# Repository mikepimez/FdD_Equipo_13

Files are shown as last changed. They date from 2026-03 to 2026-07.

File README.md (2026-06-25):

# 🌍 Equipo 13 — Fundamentos de Diseño ✦  ⁺
### Carreras de Ingeniería Ambiental / Informática / Industrial  
**Universidad Peruana Cayetano Heredia**

---

## I. Identidad & Propósito  

### 🧭 Propuesta de Valor — Diseñar para la autonomía

En el contexto urbano actual, la calidad del aire no es una condición garantizada, sino una variable invisible que afecta directamente la salud, el rendimiento cognitivo y la calidad de vida de las personas. En ciudades como Lima Metropolitana, la exposición constante a Material Particulado (PM2.5 y PM10) y a elevadas concentraciones de CO₂ en espacios cerrados configura un escenario donde respirar aire limpio deja de ser un derecho efectivo y se convierte en una condición desigual.

Diversos estudios evidencian que, incluso cuando los valores diarios no superan los estándares nacionales, los promedios anuales de contaminantes sí exceden las recomendaciones internacionales, particularmente las establecidas por la Organización Mundial de la Salud. Esta exposición prolongada incrementa el riesgo de enfermedades respiratorias, deterioro cognitivo y reducción del bienestar general.

Frente a esta realidad, nuestro enfoque no se orienta a soluciones dependientes del usuario o del contexto privilegiado, sino a sistemas capaces de operar de manera autónoma, adaptándose a entornos donde la ventilación natural resulta insuficiente o ineficiente.

Diseñamos para reducir la dependencia del comportamiento humano como factor de control ambiental, trasladando la responsabilidad hacia sistemas inteligentes que garanticen condiciones mínimas de salubridad en espacios de alta densidad.

---

### 🎯 Misión del Equipo  

Como Equipo 13, asumimos el compromiso de desarrollar soluciones de ingeniería que integren tecnología, sostenibilidad y responsabilidad social, orientadas a la protección de la salud pública en entornos urbanos.

Nuestra misión es diseñar sistemas accesibles, funcionales y técnicamente sustentados que permitan mejorar la calidad del aire en espacios cerrados, priorizando la prevención de riesgos sobre la reacción tardía. Buscamos que nuestras propuestas no solo respondan a una necesidad técnica, sino que también sean viables en contextos reales donde los recursos son limitados y las condiciones ambientales adversas.

Entendemos la ingeniería no solo como una disciplina de resolución de problemas, sino como una herramienta para reducir brechas, fortalecer la equidad y contribuir a una mejor calidad de vida.

---

### ⚙️ Enfoque de Ingeniería

Nuestro enfoque se basa en la integración de tres principios fundamentales:

- **Monitoreo en tiempo real:**  
  Evaluación continua de variables críticas como concentración de CO₂, presencia de material particulado y condiciones térmicas, utilizando sensores accesibles y calibrables.

- **Procesamiento autónomo:**  
  Implementación de sistemas de control basados en microcontroladores que permitan la toma de decisiones sin intervención constante del usuario.

- **Actuación eficiente:**  
  Activación de mecanismos de ventilación y filtración que respondan dinámicamente a las condiciones del ambiente, garantizando la renovación del aire en tiempos óptimos.

Este enfoque permite transformar datos ambientales en acciones concretas, asegurando que el sistema no solo informe sobre la calidad del aire, sino que intervenga activamente para mejorarla.

---

### 🌱 Enfoque Social & Ambiental  

El proyecto se alinea con una visión de ingeniería centrada en las personas, donde la tecnología no se desarrolla como un fin en sí mismo, sino como un medio para enfrentar problemáticas reales que afectan a la población.

La calidad del aire en espacios interiores es un problema silencioso pero crítico, especialmente en contextos educativos, transporte público y viviendas urbanas densamente ocupadas. Abordarlo implica reconocer que la salud ambiental y la salud humana están profundamente interconectadas.

Por ello, nuestro trabajo busca generar una solución que no solo sea técnicamente viable, sino también socialmente relevante, promoviendo entornos más seguros, saludables y sostenibles.

---

## II. Diagnóstico Técnico & Contextual del Problema
### 2.1 Contexto Ambiental en Lima Metropolitana

La calidad del aire en Lima Metropolitana constituye un problema estructural persistente, caracterizado por la presencia sostenida de material particulado (PM10 y PM2.5) en concentraciones que exceden los límites recomendados por organismos internacionales.

El estudio de Valdivia (2016) evidencia que, si bien los promedios diarios de PM10 pueden mantenerse dentro de los Estándares Nacionales de Calidad Ambiental (ENCA), los promedios anuales de PM10 y PM2.5 superan de manera significativa tanto los estándares nacionales como las guías de la Organización Mundial de la Salud (OMS). Esto genera una falsa percepción de seguridad normativa, ocultando que es la exposición crónica la que representa el verdadero riesgo para la salud

Asimismo, investigaciones basadas en información satelital (Oropeza & Díez, 2022) indican que Lima presenta concentraciones promedio de PM2.5 cercanas a 28 µg/m³, posicionándola entre las ciudades con mayor contaminación en Latinoamérica. Este fenómeno se ve agravado por factores meteorológicos que influyen en la dispersión de contaminantes, como la velocidad del viento y la humedad relativa (Rojas et al., 2022).

Adicionalmente, informes del Organismo de Evaluación y Fiscalización Ambiental (OEFA) han demostrado que el material particulado puede desplazarse desde fuentes industriales hacia zonas urbanas, alcanzando concentraciones superiores a 100 µg/m³ en áreas pobladas, lo que evidencia la limitada capacidad de control del entorno frente a la contaminación atmosférica.

---

### 2.2 Limitaciones de la Ventilación Natural

En entornos educativos y laborales, la ventilación natural continúa siendo la estrategia predominante para la renovación del aire. Sin embargo, su efectividad depende de variables externas como condiciones climáticas, diseño arquitectónico y comportamiento del usuario.

Estudios en contextos similares al latinoamericano (Díaz et al., 2021) demuestran que en aulas con ventilación natural, las concentraciones de CO₂ superan frecuentemente los 1400 ppm, alcanzando picos de hasta 5000 ppm en condiciones de alta ocupación. Estos valores exceden ampliamente el umbral recomendado de 1000 ppm establecido por estándares internacionales como ASHRAE.

Por otro lado, investigaciones realizadas en instituciones educativas peruanas (Huerta, 2018) evidencian que un alto porcentaje de infraestructura presenta deficiencias en estrategias pasivas de ventilación, requiriendo intervenciones adicionales para alcanzar condiciones aceptables de confort térmico.

Asimismo, evaluaciones de confort térmico en aulas universitarias (Alexander & Rivera, 2022) muestran que más del 70% de los usuarios presentan insatisfacción en ambientes sin ventilación activa, con temperaturas que superan los 27°C, lo cual afecta directamente el bienestar de los ocupantes.

Estos resultados confirman que la ventilación natural, por sí sola, no garantiza condiciones adecuadas de calidad de aire ni de confort térmico en entornos de alta ocupación.

---

### 2.3 Impacto en la Salud & Rendimiento Cognitivo

La calidad del aire interior tiene un impacto directo en la salud y en el desempeño cognitivo de los usuarios. El estudio de Satish et al. (2012) demuestra que concentraciones de CO₂ de 1000 ppm generan deterioros significativos en la toma de decisiones, mientras que niveles de 2500 ppm producen reducciones severas en múltiples indicadores cognitivos.

De manera complementaria, investigaciones en entornos escolares (Bakó-Biró et al., 2012) evidencian que el aumento en las tasas de ventilación mejora significativamente la memoria, la velocidad de respuesta y la capacidad de atención de los estudiantes.

Asimismo, estudios como el de Coley et al. (2007) indican que altos niveles de CO₂ reducen la capacidad de concentración, afectando el rendimiento académico. En conjunto, esta evidencia posiciona la calidad del aire interior como un factor crítico tanto para la salud como para el desempeño humano.

---

### 2.4 Brecha entre Normativa & Realidad Operativa

El marco normativo peruano, representado por la Ley N° 29783, establece la obligación de garantizar ambientes seguros y saludables, incluyendo la protección frente a agentes físicos como contaminantes del aire. Sin embargo, en la práctica existe una brecha significativa entre la normativa y su cumplimiento. La dependencia de sistemas pasivos, la falta de automatización y la ausencia de monitoreo continuo limitan la capacidad de controlar efectivamente la calidad del aire en espacios cerrados.

Además, la carencia de registros sistemáticos dificulta la evaluación y prevención de riesgos a largo plazo, lo que reduce la efectividad de las estrategias actuales de control ambiental.

---

### 2.5 Definición del Problema de Ingeniería

A partir del análisis contextual, ambiental y científico, se identifica el siguiente problema central:

> Se identifica una brecha crítica en el control ambiental de espacios de alta ocupación en Lima evidencia una brecha crítica en los sistemas de control ambiental. Actualmente, la ventilación pasiva y la intervención manual constante resultan insuficientes para estabilizar los niveles de CO₂ y material particulado dentro de los rangos normativos, lo que exige una transición hacia mecanismos de control más efectivos y automatizados.

Esta problemática se ve intensificada por:

* Limitaciones económicas en infraestructura
* Falta de automatización en sistemas de ventilación
* Ausencia de soluciones accesibles adaptadas al contexto local.

---

### 2.6 Justificación de la Solución & Propuesta frente a Alternativas

A partir del diagnóstico realizado, se evaluaron distintas estrategias comúnmente utilizadas para el control de la calidad del aire en espacios cerrados:

- **Ventilación natural:**
  Dependiente de condiciones externas como, por ejemplo, viento, temperatura, apertura de ventanas, demostrando ser inconsistente e insuficiente en entornos urbanos densos.
  
- **Sistemas HVAC convencionales:**
  Requieren infraestructura compleja, alto costo de instalación y mantenimiento, lo que limita su implementación en instituciones públicas y entornos de bajos recursos.
  
- **Purificadores de aire comerciales:**
  Principalmente enfocados en filtración, pero sin garantizar renovación efectiva del aire ni control de CO₂.
  
- **Sistemas inteligentes basados en IA/IoT:**
  Tecnológicamente avanzados, pero económicamente inaccesibles y sobredimensionados para el contexto de aplicación del proyecto.

Frente a estas limitaciones, se justifica el desarrollo de un sistema basado en **ventilación mecánica autónoma de bajo costo**, capaz de ejecutar la renovación activa del aire, operar sin intervención del usuario, adaptarse a distintos entornos sin requerir infraestructura especializada y mantener coherencia con el contexto socioeconómico local.

---

### 2.7 Delimitación del Alcance del Prototipo

Considerando la complejidad del problema y las restricciones del contexto, el presente proyecto se enfoca en el desarrollo de un prototipo funcional base, orientado a validar la capacidad de renovación de aire de manera autónoma.

Componentes como:

* Almacenamiento de datos a largo plazo
* Interfaces digitales
* Optimización mediante algoritmos inteligentes

son reconocidos como líneas de desarrollo futuras, pero no forman parte del núcleo funcional requerido para la validación inicial del sistema.
Esta decisión responde a un criterio de ingeniería que prioriza la validación de la función crítica del sistema antes de su expansión.

---

## III. Alineación con los Objetivos de Desarrollo Sostenible (ODS)

El desarrollo del sistema **Eco-Vent** se fundamenta en los principios de la Agenda 2030 de la Organización de las Naciones Unidas. Integramos un enfoque de ingeniería orientado a la salud, la sostenibilidad y la equidad, estableciendo una relación directa entre nuestra solución técnica y las metas globales de desarrollo.

### 🏥 ODS 3 — Salud y Bienestar
> **Meta 3.9:** Reducir sustancialmente el número de muertes y enfermedades producidas por productos químicos peligrosos y la contaminación del aire, el agua y el suelo.

El proyecto contribuye directamente a esta meta mediante la mitigación de riesgos asociados a la exposición crónica a contaminantes críticos como el **Material Particulado (PM10)** y concentraciones elevadas de **CO₂**. Al automatizar la renovación del aire en espacios cerrados, Eco-Vent reduce la prevalencia de afecciones respiratorias y previene el deterioro cognitivo identificado en entornos de alta saturación.

### 🏙️ ODS 11 — Ciudades y Comunidades Sostenibles
> **Meta 11.6:** Reducir el impacto ambiental negativo per cápita de las ciudades, prestando especial atención a la calidad del aire y la gestión de los desechos.

Eco-Vent aborda la problemática de la habitabilidad en micro-entornos urbanos densamente poblados como, por ejemplo, aulas, transporte masivo y viviendas cerca de focos industriales, etcétera. Nuestra solución democratiza el acceso a aire seguro mediante un sistema de **bajo costo y fácil implementación**, fortaleciendo la resiliencia de la infraestructura urbana en contextos donde los sistemas HVAC convencionales son técnica o económicamente inviables.

### 🌿 ODS 13 — Acción por el Clima
> **Meta 13.3:** Mejorar la educación, la sensibilización y la capacidad humana e institucional respecto de la mitigación del cambio climático y la adaptación a él.

El sistema incorpora monitoreo ambiental en tiempo real, promoviendo indirectamente la conciencia sobre la calidad del aire y fomentando el uso de soluciones tecnológicas de bajo consumo energético para el control ambiental. Al utilizar ventilación mecánica controlada por demanda, optimizamos el uso de recursos y promovemos una respuesta eficiente frente a la variabilidad térmica y química del entorno, fomentando el uso de tecnologías sostenibles para el control ambiental.

---

## IV. Requerimientos e Ingeniería (Metodología VDI 2206)

En esta sección, el problema identificado se traduce en criterios concretos de diseño siguiendo la metodología VDI 2206. Se establecen las funciones del sistema, los requerimientos asociados y los parámetros medibles que permitirán validar su desempeño.

Este enfoque asegura que el desarrollo del sistema se base en lo que debe hacer antes de definir cómo se implementa.

---

### 4.1 Funciones del Sistema

El sistema Eco-Vent se define a partir de una función principal y un conjunto de funciones secundarias que estructuran su comportamiento.

**Función principal:**
- Mantener condiciones adecuadas de calidad del aire interior mediante ventilación mecánica controlada.

**Funciones secundarias:**
- Detectar variables ambientales (CO₂, temperatura y humedad).
- Evaluar la calidad del aire en tiempo real en función de umbrales definidos.
- Tomar decisiones de control de manera autónoma sin intervención del usuario.
- Ejecutar la renovación activa del aire mediante actuadores.
- Comunicar el estado del sistema a través de indicadores visuales.

Estas funciones definen el comportamiento esperado del sistema y constituyen la base para el establecimiento de requerimientos.

---

### 4.2 Lista de Exigencias del Sistema

A partir de las funciones definidas, se establecen los requerimientos que el sistema debe cumplir. Estos se clasifican en requerimientos de usuario, técnicos y restricciones.

#### Requerimientos de Usuario

- Operar de forma autónoma durante al menos 8 horas continuas sin intervención del usuario.
- Mantener condiciones de aire saludable en espacios cerrados (CO₂ < 1000 ppm).
- Proporcionar información clara e inmediata sobre la calidad del aire mediante indicadores visuales.
- Ser accesible económicamente para su implementación en entornos reales.

---

#### Requerimientos Técnicos

- Medir concentración de CO₂ en un rango mínimo de 400 a 5000 ppm.
- Medir temperatura y humedad relativa del entorno.
- Procesar datos en tiempo real con un tiempo de respuesta ≤ 5 minutos ante condiciones críticas.
- Activar automáticamente el sistema de ventilación al superar los umbrales establecidos.
- Mantener un consumo energético ≤ 15 W durante operación continua.
- Garantizar funcionamiento continuo durante periodos prolongados (≥ 8 horas).
- Integrar un sistema de señalización visual con tres estados (normal, moderado, tóxico).
- Permitir el registro básico de datos para evaluación del desempeño del sistema.

---

#### Restricciones del Sistema

- Costo total del prototipo ≤ 150 USD.
- Uso de componentes disponibles en el mercado local.
- Adaptabilidad a distintos tipos de espacios, por ejemplo, aulas u oficinas.
- Diseño compacto y de fácil instalación.
- Mantenimiento simple sin requerir personal altamente especializado.

---

### 4.3 Criterios Cuantitativos de Diseño

Para validar el desempeño del sistema, se establecen indicadores medibles que permiten verificar el cumplimiento de su función principal:

- Concentración de CO₂ objetivo: < 1000 ppm.
- Umbral de activación del sistema: ≥ 1000 ppm.
- Tiempo máximo de respuesta del sistema: ≤ 5 minutos.
- Autonomía mínima de operación: ≥ 8 horas continuas.
- Consumo energético máximo: ≤ 15 W.
- Capacidad de renovación de aire definida en función del volumen del espacio, sea la tasa de renovación de aire por hora, ACH.

Estos criterios permiten evaluar objetivamente el funcionamiento del sistema durante la fase de validación experimental.

---

### 4.4 Vigilancia Tecnológica y Análisis de Patentes

Como parte del proceso de diseño, se realizó una revisión de soluciones existentes para identificar tendencias tecnológicas y oportunidades de diferenciación. El análisis evidencia que las soluciones actuales presentan las siguientes características:

- Enfoque predominante en el monitoreo de variables como CO₂ y temperatura.
- Uso de tecnologías avanzadas basadas en inteligencia artificial e IoT.
- Integración en infraestructuras complejas de edificios inteligentes.

A partir de ello, se identifican los siguientes vacíos:

- **Limitado enfoque en material particulado (PM2.5 / PM10):**  
  Las soluciones priorizan gases, sin considerar contaminantes sólidos relevantes en el contexto local.

- **Predominio del monitoreo sobre la acción:**  
  Muchos sistemas informan, pero no intervienen directamente sobre el ambiente.

- **Alta complejidad y costo:**  
  Las soluciones existentes dificultan su implementación en entornos de bajos recursos.

---

### 4.5 Posicionamiento de la Solución

Frente a estas limitaciones, el sistema Eco-Vent se define por:

- Acción directa sobre el ambiente mediante ventilación mecánica controlada.
- Automatización sin dependencia de sistemas complejos de inteligencia artificial.
- Diseño accesible, adaptable y de bajo costo.
- Enfoque en contexto real, priorizando funcionalidad sobre complejidad tecnológica.

Este enfoque establece una propuesta coherente con el problema identificado y orientada a su implementación en escenarios reales.

---

## V. Propuesta de Solución — Sistema Eco-Vent

### 5.1 Concepto General del Sistema

El sistema **Eco-Vent** se define como un dispositivo de ventilación mecánica autónoma de bajo costo, diseñado para mejorar la calidad del aire en espacios cerrados mediante la integración de monitoreo ambiental, procesamiento de datos y actuación automática.

A diferencia de soluciones basadas únicamente en monitoreo, Eco-Vent incorpora un enfoque activo de control ambiental, en el cual el sistema no solo detecta condiciones desfavorables, sino que interviene directamente sobre el entorno mediante la renovación del aire.

El sistema está orientado a operar de manera continua y sin intervención del usuario, adaptándose dinámicamente a las condiciones del ambiente interior.

---

### 5.2 Arquitectura General del Sistema

Eco-Vent se estructura como un sistema mecatrónico compuesto por tres bloques funcionales principales:

#### 1. Módulo de Sensado

Encargado de la adquisición de variables ambientales relevantes para la evaluación de la calidad del aire. Incluye sensores para:

* Temperatura y humedad relativa
* Escalabilidad en concentración de CO₂ y material particulado

Este módulo transforma variables físicas del entorno en señales eléctricas que pueden ser procesadas por el sistema.

---

#### 2. Módulo de Procesamiento y Control

Implementado mediante un microcontrolador, este módulo constituye el núcleo de decisión del sistema. Sus funciones principales son:

* Recepción y procesamiento de datos ambientales
* Evaluación de condiciones en función de umbrales predefinidos
* Ejecución de lógica de control autónoma

El sistema compara continuamente las variables medidas con valores de referencia, permitiendo determinar el estado del ambiente en tiempo real.

---

#### 3. Módulo de Actuación

Encargado de ejecutar la respuesta del sistema frente a condiciones desfavorables. Incluye:

* Activación de ventiladores para la renovación del aire
* Generación de flujo de aire hacia el exterior o hacia zonas de intercambio

Este módulo convierte la decisión del sistema en una acción física sobre el entorno.

---

#### 4. Módulo de Interfaz

Permite la comunicación del estado del sistema hacia el usuario mediante:

* Indicadores visuales (LEDs)
* Señales de alerta según el nivel de calidad del aire

Su función es proporcionar información clara sin requerir interacción activa.

---

### 5.3 Lógica de Funcionamiento del Sistema

El funcionamiento de Eco-Vent se basa en un ciclo continuo de cuatro etapas:

1. **Adquisición de datos:**
   El sistema mide variables ambientales del entorno en tiempo real.

2. **Evaluación de condiciones:**
   Los datos son comparados con umbrales establecidos (por ejemplo, CO₂ ≥ 1000 ppm o condiciones térmicas desfavorables).

3. **Toma de decisión:**
   El sistema determina si es necesario activar la ventilación.

4. **Actuación:**
   Se activa el sistema de ventilación mecánica hasta restablecer condiciones aceptables.

Este ciclo se ejecuta de forma autónoma, garantizando una respuesta dinámica ante cambios en el ambiente.

---

### 5.4 Alcance del Prototipo de Validación

El prototipo desarrollado en esta etapa tiene como objetivo validar el principio de funcionamiento del sistema, más no su implementación completa. Por ahora, la validación se centra en:

* Adquisición de variables ambientales básicas (temperatura y humedad)
* Procesamiento de datos mediante microcontrolador
* Ejecución de lógica de control basada en umbrales
* Activación de un actuador (ventilador o señal visual)

Este enfoque permite demostrar la viabilidad del sistema en términos de:

* Sensado
* Procesamiento
* Decisión
* Actuación

Componentes como sensores de CO₂, medición de material particulado, almacenamiento de datos y optimización avanzada se consideran extensiones futuras del sistema.

---

### 5.5 Justificación de la Arquitectura Propuesta

La arquitectura de Eco-Vent responde directamente a las limitaciones identificadas en el análisis del problema:

* Reduce la dependencia del usuario mediante automatización
* Evita la complejidad de sistemas HVAC tradicionales
* Mantiene un costo accesible mediante el uso de microcontroladores
* Permite escalabilidad hacia sistemas más complejos

Este diseño equilibra funcionalidad, costo y viabilidad, asegurando coherencia con el contexto de aplicación del proyecto.

---

### 5.6 Proyección de Desarrollo (Roadmap)

El desarrollo del sistema se plantea en etapas progresivas:

**Fase 1 — Validación funcional (actual):**

* Implementación de prototipo básico
* Verificación de lógica de control
* Activación de actuadores simples

**Fase 2 — Integración de sensores avanzados:**

* Incorporación de sensores de CO₂
* Medición de material particulado (PM2.5 / PM10)

**Fase 3 — Optimización del sistema:**

* Mejora en eficiencia energética
* Ajuste dinámico de umbrales

**Fase 4 — Expansión del sistema:**

* Integración de registro de datos
* Conectividad y monitoreo remoto
* Interfaces digitales avanzadas

Este enfoque permite evolucionar desde un prototipo funcional hacia una solución completa y escalable.

# ✦  ⁺

## 📸 Fotografía del Equipo

<p align="center">
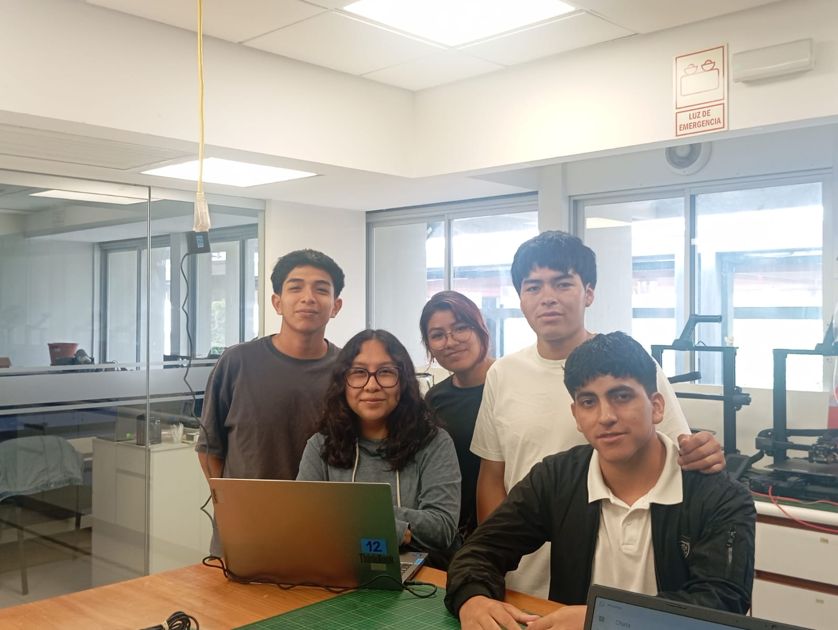
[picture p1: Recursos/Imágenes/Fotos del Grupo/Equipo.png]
Fotografía del Equipo 13
  
  <br>
  <em>Figura 1. Integrantes del equipo 13 en sesión de trabajo</em>
</p>

---

## 👥 Integrantes

| Foto | Apellidos y Nombres | Carrera | Correo |
| :--- | :--- | :--- | :--- |
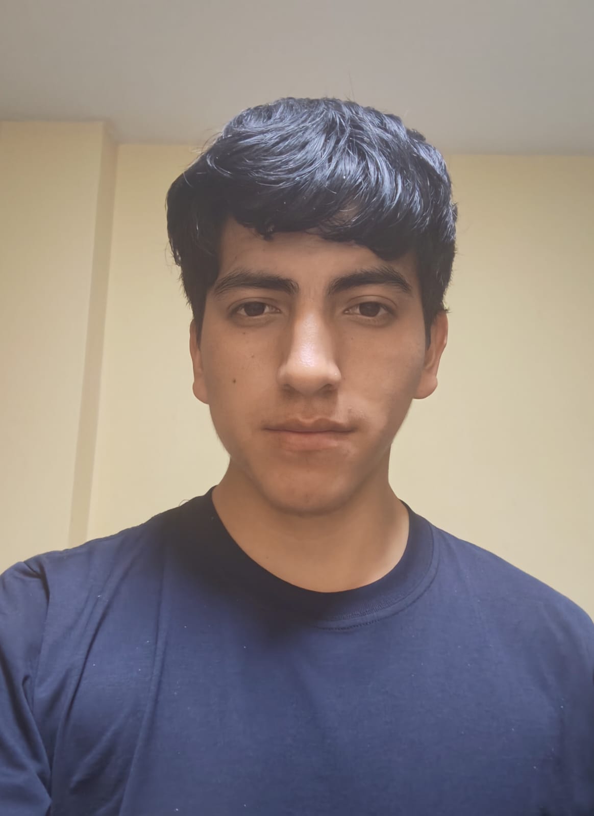
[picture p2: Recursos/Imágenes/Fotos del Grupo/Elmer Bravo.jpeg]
Elmer Bravo
|  | **Bravo Tumbay**, Elmer David | Ing. Informática | elmer.bravo@upch.pe |
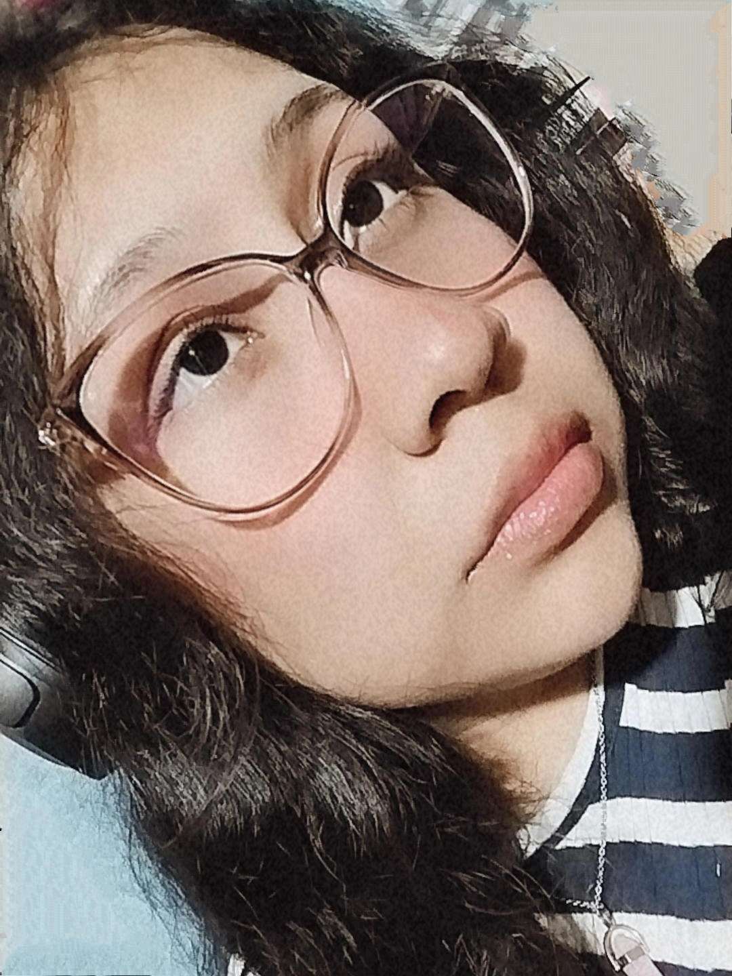
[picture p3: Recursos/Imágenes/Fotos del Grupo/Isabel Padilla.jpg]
Isabel Padilla
|  | **Padilla Romero**, Isabel Antonella | Ing. Informática | isabel.padilla@upch.pe |
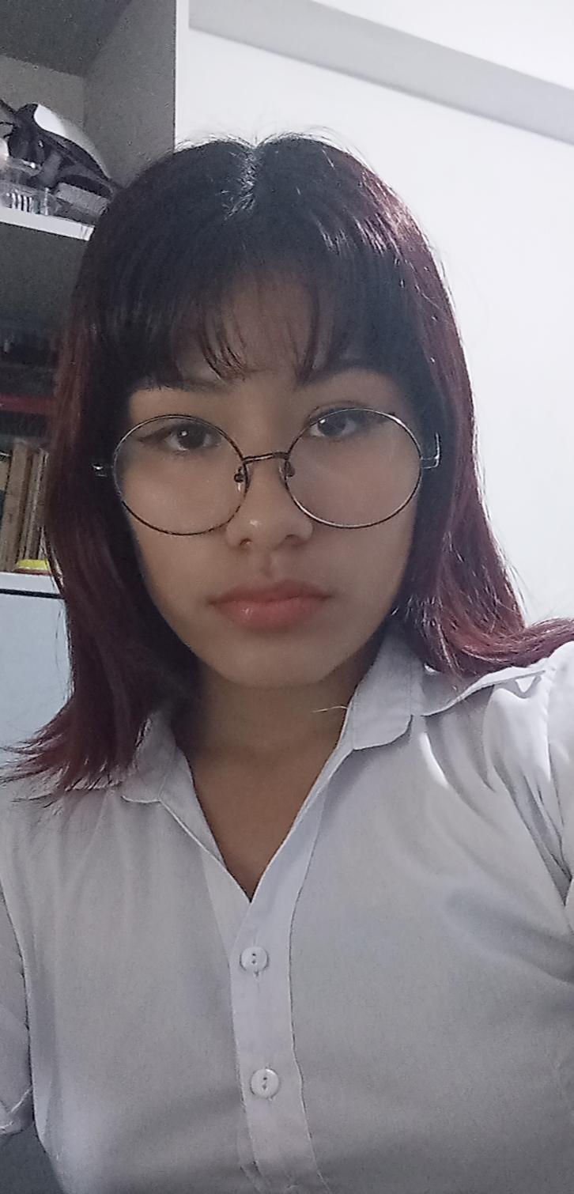
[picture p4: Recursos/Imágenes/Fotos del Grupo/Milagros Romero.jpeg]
Milagros Romero
|  | **Romero Yllaconza**, Milagros Lucero | Ing. Industrial | milagros.romero@upch.pe |
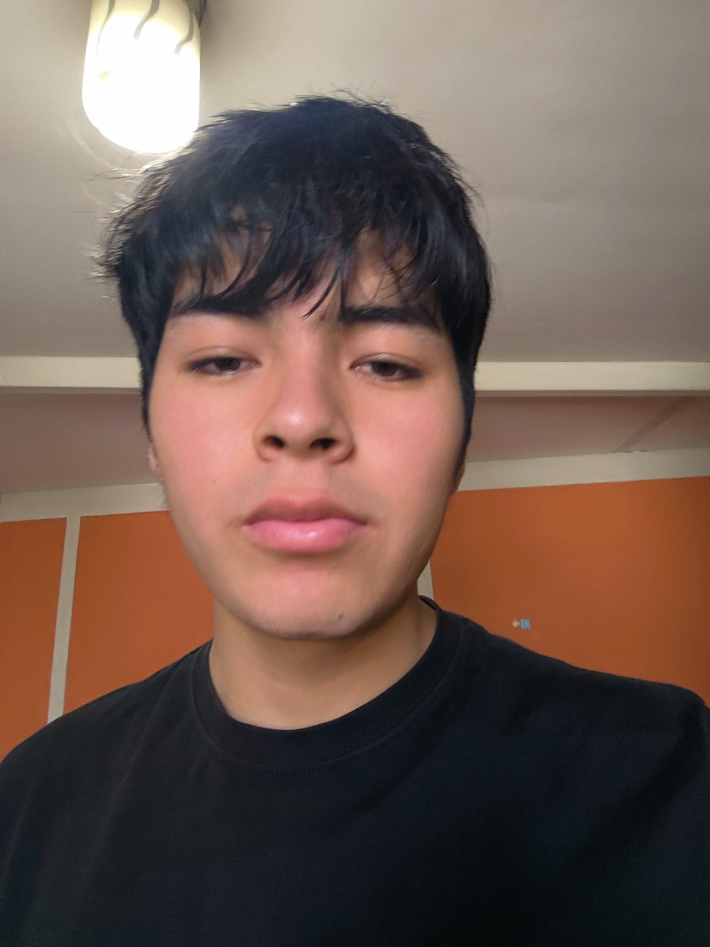
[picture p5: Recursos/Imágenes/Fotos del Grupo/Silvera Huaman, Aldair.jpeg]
Aldair Silvera
|  | **Silvera Huaman**, Aldair | Ing. Ambiental | aldair.silvera@upch.pe |
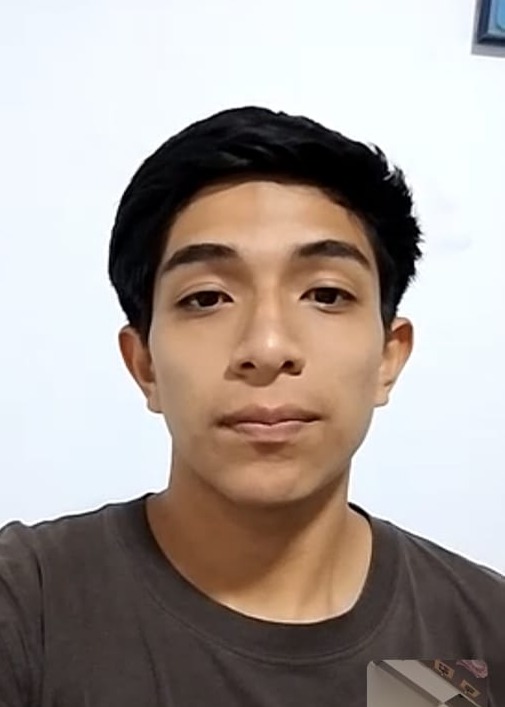
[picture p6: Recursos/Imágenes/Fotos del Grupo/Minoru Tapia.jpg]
Minoru Tapia
|  | **Tapia Gómez**, Minoru Takeshi | Ing. Informática | minoru.tapia@upch.pe |

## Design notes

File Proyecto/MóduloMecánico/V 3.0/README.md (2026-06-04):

# Link Onshape Modelado 3D
## https://cad.onshape.com/documents/7c770d6f8d080e2502558632/w/8b1f14da12b92f794561f62a/e/0e05e1922821607debe3d5e9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

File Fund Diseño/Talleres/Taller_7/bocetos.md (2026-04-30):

Descripción del Prototipo Eco-Vent

El Eco-Vent es un sistema de ventilación inteligente diseñado para mejorar la calidad del aire en espacios cerrados mediante la detección 
y control automático de contaminantes como CO₂ y gases nocivos.

El funcionamiento del sistema se basa en la integración de sensores ambientales (como el MQ135), un microcontrolador (Arduino) y un sistema 
de ventilación mecánica. Los sensores monitorean continuamente las condiciones del aire y envían la información al microcontrolador, el cual
evalúa los niveles de contaminación y determina cuándo es necesario activar el ventilador.

A diferencia de un ventilador convencional, el Eco-Vent no opera de forma constante, sino que responde de manera automática ante condiciones 
desfavorables del aire, optimizando el consumo energético y mejorando el confort del usuario.

En cuanto a su diseño físico, se plantean tres propuestas:

Diseño esquinero: permite su instalación en espacios reducidos, aprovechando áreas poco utilizadas y facilitando la distribución del aire hacia 
el centro del ambiente.
Diseño portátil: incorpora características de movilidad y alimentación por USB o batería, permitiendo su uso en diferentes entornos.
Diseño estilo natural: prioriza la integración estética con el entorno, utilizando materiales simples y un diseño minimalista adaptable a hogares
y oficinas.

Es importante destacar que el sistema no reemplaza la ventilación natural, sino que la complementa. Su función principal es detectar condiciones de
baja calidad del aire y activar mecanismos que favorezcan la renovación del mismo, ya sea mediante la circulación interna o facilitando su expulsión 
cuando existe una salida de aire (ventanas, rejillas o ductos).

De esta manera, el Eco-Vent contribuye a mejorar el bienestar, la concentración y la salud de los usuarios en ambientes cerrados, alineándose con 
soluciones sostenibles y de bajo costo.

# Taller 7 – Eco-Vent
## Bocetos del prototipo

Bocetos Eco-Vent

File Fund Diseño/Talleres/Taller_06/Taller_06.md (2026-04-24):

# Taller 6: Desk Research

## 1. Definición del Problema Técnico
¿Cómo diseñar e implementar un sistema de gestión atmosférica autónomo, de bajo costo y alta eficiencia, que purifique y renueve el aire en entornos saturados, garantizando niveles óptimos de CO2 y Material Particulado (PM10) según los estándares de la OMS y la Ley N° 29783, integrando una base de datos estadística para la prevención de riesgos?

---

## 2. Matriz de Desk Research

| N° | Fuente | Autor / Institución | Año | Referencia | Estado de tecnología encontrado | Exigencia o requisito identificado | Restricción o limitación | Función principal | Aplicación al proyecto |
|:--:|:---|:---|:---:|:---|:---|:---|:---|:---|:---|
| 1 | Informe OEFA N° 00180-2023 | OEFA | 2023 | [Informe Técnico OEFA 2023](https://repositorio.oefa.gob.pe/items/8f5525af-dd99-4b53-bb9c-635a1b3a9b2c) | Monitoreo de dispersión de PM10 hacia zonas pobladas. | Activación mecánica ante > 100 µg/m³ de PM10. | Necesidad de pre-filtrado físico para aire exterior. | Evaluar la dispersión de partículas contaminantes en el aire. | Define umbral de seguridad y justifica el uso de ductos. |
| 2 | Ventilation rates in schools | Bakó-Biró et al. | 2012 | [Artículo Científico (2012)](https://www.sciencedirect.com/science/article/pii/S0360132311002617) | Relación CO2 (5000 ppm) y reducción de memoria (15%). | Flujo mínimo de 8 L/s por persona (CO2 < 1000 ppm). | El sistema debe ser autónomo para evitar fatiga sensorial. | Optimizar el rendimiento cognitivo mediante la renovación de aire. | Establece la lógica de control y Set Point de CO2. |
| 3 | Confort Térmico UNMSM | Alexander & Poma | 2022 | [Tesis UNMSM (2022)](https://industrial.unmsm.edu.pe/investigacionfii/wp-content/uploads/2021/07/07.-TI-EPISST-TINEO-ZAMORA.pdf) | Evaluación de sensación térmica (Metodología Fanger). | Temperatura operativa máxima de 27°C (Costa peruana). | 76% de insatisfacción en ambientes sin ventilación activa. | Determinar el nivel de bienestar térmico en espacios cerrados. | Justifica el uso de sensor DHT11 para estrés térmico. |
| 4 | Ley N° 29783 | Congreso Perú | 2011 | [Plataforma El Peruano](https://diariooficial.elperuano.pe/Normas/obtenerDocumento?idNorma=38) | Marco legal de Seguridad y Salud en el Trabajo. | Garantizar ambientes libres de agentes físicos nocivos. | El dispositivo debe generar registros para auditorías. | Establecer normas de protección para la salud de los usuarios. | Define la función de base de datos y reporte estadístico. |
| 5 | Is CO2 an Indoor Pollutant? | Satish, U. et al. | 2012 | [Publicación EHP (2012)](https://pmc.ncbi.nlm.nih.gov/articles/PMC3548274/) | Impacto de CO2 en toma de decisiones (1000 ppm). | El sensor debe detectar variaciones de 400 ppm. | Renovación de aire en < 5 min tras detección de riesgo. | Analizar el efecto de gases de ocupación en la toma de decisiones. | Valida la elección de MQ-135 y procesamiento Arduino. |

---

## 3. Lista de Exigencias

| Tipo | Exigencia | Descripción |
|:---:|:---|:---|
| **D** | Automatización | El sistema debe actuar sin intervención humana. |
| **E** | Filtración | Debe contar con una etapa de purificación mecánica. |
| **E** | Normativa | Cumplir con CO2 < 1000 ppm y PM10 < 100 µg/m³. |
| **D** | Bajo Costo | Materiales accesibles para instituciones públicas. |
| **E** | Portabilidad | Diseño compacto para instalación en ductos de aulas o buses. |

---

## 4. Estructura Funcional

### A. Caja Negra
* **Entradas:** Aire viciado (CO2/PM10), Energía (5V/Powerbank), Datos de sensores.
* **Procesamiento:** Sistema Eco-Vent 13 (Lógica de control + Filtración).
* **Salidas:** Aire renovado/purificado, Registro estadístico de calidad, Alerta visual.

### B. Funciones Principales
1.  **Captar contaminante:** Censar niveles de CO2 y PM10 en tiempo real.
2.  **Filtrar aire:** Retener partículas sólidas del flujo de entrada.
3.  **Renovar flujo:** Activar la extracción mecánica de aire viciado.
4.  **Registrar datos:** Almacenar estadísticas para prevención de riesgos.

---

## 5. Reformulación de la Oportunidad de Diseño
¿Cómo podríamos diseñar un sistema ambiental eficiente, sostenible y normativamente compatible (Ley N° 29783) que automatice la renovación y purificación del aire para proteger la capacidad cognitiva y la salud respiratoria en espacios de alta densidad?

---

## 6. Conclusión
Los hallazgos del Desk Research confirman que la ventilación natural en Lima es insuficiente frente a la carga de PM10 y CO2. La fase de concepción de la solución debe priorizar un sistema **"In-Out"** (Entrada filtrada / Salida forzada) que sea autónomo, eliminando la dependencia del factor humano para garantizar un ambiente seguro.

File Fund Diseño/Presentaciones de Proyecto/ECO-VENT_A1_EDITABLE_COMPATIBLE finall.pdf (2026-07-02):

# ECO-VENT:

# Sistema automático de ventilación para mejorar las condiciones del aire interior mediante sensores de calidad del aire y temperatura

## Autores: Milagros Romero, Minoru Tapia, Isabel Padilla, David Bravo y Aldair Silva Curso: Fundamentos de Diseño Carreras: Ingeniería Ambiental, Ingeniería Industrial e Ingeniería Informática

Docentes: Marco Antonio Mugaburu Celi; Julissa Elvira Venancio Huerta; Domingo Vladimir Flores Robles; Víctor

## Alberto Huanambal Sovero

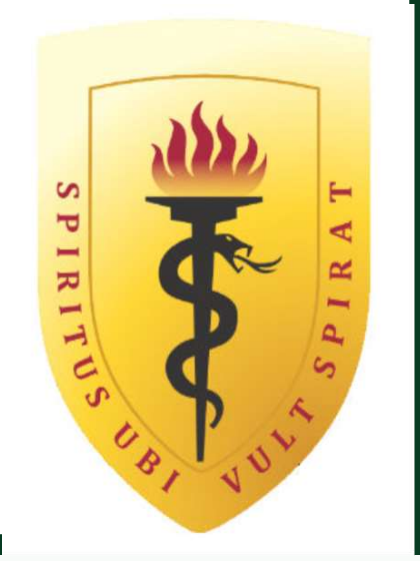
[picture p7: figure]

### 1 INTRODUCCIÓN GENERAL

La ventilación insuficiente en aulas y oficinas favorece la acumulación de contaminantes y puede afectar el confort y la concentración de las personas. En respuesta a esta problemática, se desarrolló ECO-VENT, un prototipo que monitorea la calidad del aire y la temperatura para activar la ventilación de forma automática [1–3].

## Calidad del aire

Confort y
concentración

Solución
sostenible

## 2 OBJETIVOS

## Objetivo general

Diseñar e implementar un prototipo de ventilación automática que monitoree las condiciones del aire interior y active la ventilación cuando los valores registrados superen los umbrales programados.

## Objetivos específicos

1

Integrar un sensor de calidad del aire (MQ-135) y un sensor de temperatura y humedad (DHT11) con una tarjeta de desarrollo ESP32.

2

Programar el monitoreo de variables ambientales y la activación automática de cuatro ventiladores mediante un Módulo Relay 5V - 2 canales.

3

Evaluar el funcionamiento del prototipo mediante mediciones de respuesta, variación de lecturas, dimensiones, peso y operación del sistema.

# 3 PROPUESTA DE INNOVACIÓN

1

Sensado

→

2

Procesamiento

→

3

Alerta visual

→

4

Ventilación

→

5

Wi-Fi
Sensor de calidad
del aire (MQ-135)
y sensor de
temperatura y
humedad
(DHT11).

El ESP32 procesa
las lecturas y las
compara con los
umbrales
programados.

LED verde: dentro
del rango.
LED amarillo: alerta.
LED rojo: valor por
encima del umbral.

Activación de
cuatro
ventiladores
mediante un
módulo relé de
5 V y 2 canales.

Visualización de
las lecturas y
ajuste de los
umbrales.

Componentes principales

ESP32 | MQ-135 | DHT11

### 4 ventiladores

Relay 5V

### 2 canales

3 LED | LM2596S | Carbón
activado
Valor diferencial
de ECO-VENT
- Activación
automática
- Alertas LED
- Temperatura y
humedad
- Umbrales ajustables
- Aplicación móvil /
Wi-Fi

Figura 1. Representación del diseño final del prototipo ECO-VENT.

### 4 METODOLOGÍA DE INVESTIGACIÓN

Se empleó una metodología de diseño de ingeniería basada en VDI 2206, organizada en cuatro etapas [6].

1

Identificación del problema y requerimientos

Necesidades del usuario, espacio de aplicación y componentes.

2

## Diseño e integración

Carcasa, sensores, ESP32,
LED, relé, filtro y ventiladores.

3

## Programación y ajuste

Lectura de sensores,
activación, umbrales y
monitoreo Wi-Fi.

4

## Evaluación funcional

Prueba en ambiente cerrado y registro de variaciones.

## Condiciones de prueba

- Ambiente cerrado: 30 m³
- Personas: 5
- Duración: 20 min
- Registro: cada 2 min
- Humo de encendedor
- Sistema encendido toda la prueba

# Ámbito de referencia:

## Espacios cerrados pequeños de 30–35 m³ (aprox. 12–14 m² con altura de 2.4–2.5 m), como aulas pequeñas, oficinas o

salas de estudio [8,9].

# 5 RESULTADOS

# ↓ 470 ADC

1950 → 1480 ADC

↓ 0.6 °C

27.8 → 27.2 °C

↓ 3 p.p.

64 % → 61 %

# 2 s

Tiempo de activación

Ruido operativo preliminar

# 33.2 dB(A)

Medido a 1 m durante 60 s

Criterio de referencia

# ≤ 35 dB(A)

Ruido de fondo para aulas [7,8]

El valor de 33.2 dB(A) se compara de forma orientativa con el criterio de 35 dB(A). La verificación final debe realizarse con sonómetro calibrado.

## Tabla 1. Resultados de la prueba funcional

Parámetro | Inicial | Final | Mejora
Lectura sensor | 1950 ADC 1480 ADC ↓470 ADC
Temperatura | 27.8 °C | 27.2 °C | ↓0.6 °C
Humedad | 64 % | 61 % | ↓3 p.p.
Respuesta | 0 | 2 s | Automática
Ventiladores | Apagados | Encendid os | Correcto

La disminución de 470 ADC representa una variación en la respuesta del sensor MQ-135; no equivale a una medición directa de CO₂ ni a un porcentaje exacto de mejora de la calidad del aire.

## 6 CONCLUSIONES, RECOMENDACIONES Y LECCIONES APRENDIDAS

## Conclusiones

- Se construyó un prototipo funcional capaz de
monitorear las condiciones del aire y activar
automáticamente la
ventilación.
- Durante la prueba se
observó una reducción en la lectura del sensor, la
temperatura y la humedad
relativa.
- El sistema presentó un
tiempo aproximado de
respuesta de 2 segundos y
un funcionamiento estable.

## Recomendaciones

- Incorporar en futuras
versiones un sensor específico de CO₂ tipo NDIR.
- Realizar más pruebas en
distintos ambientes y durante periodos prolongados.
- Calibrar el sistema con
equipos especializados para mejorar la interpretación de las lecturas.
- Verificar el nivel sonoro con un sonómetro calibrado en
futuras evaluaciones.

## Lecciones aprendidas

- La organización del cableado mejora la seguridad y el
mantenimiento.
- La estabilización y calibración de los sensores es clave para interpretar los resultados.
- Los umbrales deben ajustarse mediante pruebas sucesivas.

## Referencias (Vancouver)

1. World Health Organization. WHO global air quality guidelines: particulate matter (PM2.5 and PM10), ozone, nitrogen dioxide, sulfur dioxide and carbon monoxide [Internet]. Geneva: World Health Organization; 2021 [citado 24 jun 2026].
2. United Nations. The Sustainable Development Goals Report 2023: special edition [Internet]. New York: United Nations; 2023 [citado 24 jun 2026].
3. American Society of Heating, Refrigerating and Air-Conditioning Engineers. Ventilation for acceptable indoor air quality: ASHRAE Standard 62.1 [Internet]. Atlanta: ASHRAE; 2019 [citado 24 jun 2026].
4. Pressac Sensing. CO₂, humidity and temperature wireless sensor [Internet]. Nottingham: Pressac Communications Ltd.; [citado 24 jun 2026].
5. Aosong Electronics Co., Ltd. DHT11 temperature and humidity sensor: technical data sheet [Internet]. Guangzhou: Aosong Electronics; [citado 24 jun 2026].
6. Berglund B, Lindvall T, Schwela DH. Guidelines for community noise [Internet]. Geneva: World Health Organization; 1999 [citado 24 jun 2026].
7. Armstrong World Industries. Classroom acoustics and ANSI Standard S12.60 [Internet]. Lancaster: Armstrong World Industries; [citado 24 jun 2026].
8. Stinson BW. Developing and testing low-cost air cleaners for safer spaces during wildfires [tesis en Internet]. Portland: Portland State University; 2023 [citado 24 jun 2026].
9. Li G, inventor. Catalyst for disinfection, sterilization and purification of air, and preparation method thereof. United States patent US10183187B2. 2019 Jan 22.

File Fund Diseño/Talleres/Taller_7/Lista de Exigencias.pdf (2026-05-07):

## LISTA DE EXIGENCIAS

29/04/2026

29/04/2026

29/04/2026

29/04/2026

29/04/2026

29/04/2026

29/04/2026

29/04/2026

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
Condición del aire interior Temperatura y humedad ambiental Energía eléctrica de alimentación

Aire ventilado y renovado
Flujo de ventilación generado
Estado de funcionamiento del sistema

Docentes del curso – Fundamentos de Diseño (FdD), UPCH

El sistema puede operar con energía solar mediante un panel fotovoltaico de pequeña escala, reduciendo su dependencia de la red eléctrica.

La estructura del dispositivo permite su fijación en superficies planas mediante tornillos o cinta de montaje de doble cara.

El dispositivo tendrá dimensiones máximas de 200×150×80 mm (L×A×P), permitiendo su instalación discreta en paredes o techos de aulas y oficinas. [4]

El sistema opera con una fuente de alimentación de 5V DC, pudiendo conectarse mediante cable USBC, adaptador AC/DC o powerbank, lo que permite su uso en cualquier entorno con o sin acceso a tomacorriente.

Detectar automáticamente niveles elevados de CO₂ (≥ 1000 ppm) y temperatura en espacios cerrados de alta ocupación, y activar un sistema de ventilación mecánica sin intervención humana para restablecer condiciones de calidad del aire aceptables. [1, 2, 3]

El peso total del dispositivo es inferior a 1 kg, incluyendo carcasa, sensores y ventilador. Este criterio es definido por el equipo de diseño para garantizar una instalación segura mediante fijación mural sin anclajes especializados.

Eco-Vent: Sistema mecatrónico de ventilación automática para mejorar la calidad del aire interior en
espacios cerrados mediante sensores de CO₂ y temperatura. | 06/05/2026
| Revisado:
| 06/05/2026

Todos

Minoru

Minoru

Aldair

Elmer

Elmer

Rev 2.0

Fecha

CLIENTE:

ENERGÍA

SEÑALES

FUERZAS

PROYECTO:

GEOMETRÍA

E
/
D

FUNCIÓN PRINCIPAL

Salidas:

ELECTRÓNICA (Hardware)

Entradas:

DESCRIPCIÓN

Fecha:

Edición:

Responsable

Todos

Todos

Elaborado: Por
equipo Eco-Vent
-Aldair Silvera
-Isabel Padilla
-Elmer Bravo
-Milagros Romero
-Minoru Tapia

•
•
•

•
•
•

29/04/2026

29/04/2026

29/04/2026

29/04/2026

29/04/2026

29/04/2026

29/04/2026

29/04/2026

29/04/2026

29/04/2026

29/04/2026

29/04/2026

29/04/2026

29/04/2026

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
El procesamiento de señales de los sensores y el control del actuador se realiza mediante el microcontrolador ESP32-WROOM-32, alimentado a 5V por USB-C.

El algoritmo de control compara continuamente la lectura del sensor MQ-135 con el umbral de 1000 ppm de CO₂, activando el ventilador de forma autónoma al superarlo. [3]

El dispositivo no genera riesgo eléctrico ni mecánico para los usuarios del espacio. Los componentes de alta tensión del relay están aislados y protegidos dentro de la carcasa cerrada.

El sistema no emite ruido superior a 35 dB durante la operación del ventilador, valor recomendado por la OMS y la norma ANSI S12.60 para aulas, evitando interferir con actividades académicas. [6, 7]

Se recomienda la revisión y recalibración del sensor MQ-135 cada 6 meses para asegurar precisión en la lectura de CO₂ a lo largo del tiempo.

El dispositivo puede instalarse en paredes o techos de aulas y oficinas sin requerir herramientas especializadas ni personal técnico altamente calificado.

El sistema de fijación mural debe soportar el peso total del dispositivo (< 1 kg) de forma segura y estable durante su operación continua.

El dispositivo puede ser reubicado entre distintos espacios (aulas, oficinas) sin necesidad de modificar su configuración interna, adaptándose a distintos entornos de alta ocupación.

El sistema registra y almacena el historial de lecturas para análisis posterior de la calidad del aire. Esta función es considerada una extensión futura del sistema según el roadmap de desarrollo del proyecto.

Los componentes del prototipo (ESP32-WROOM-32, sensor MQ-135, sensor DHT11, relay, ventilador, cables jumper/dupont, protoboard de 400 puntos) son accesibles en el mercado local peruano.

El ensamblaje del prototipo se realiza sin soldadura, utilizando protoboard de 400 puntos y cables jumper/dupont, lo que facilita el montaje, desmontaje y modificación de conexiones durante la fase de validación.

El sensor MQ-135 debe ser calibrado antes de su uso en condiciones de aire limpio (~400 ppm de CO₂)

La operación del sistema es completamente autónoma, sin requerir intervención del usuario para activar o detener la ventilación, reduciendo la dependencia del comportamiento humano como factor de control ambiental.

La carcasa del dispositivo tiene bordes redondeados y acabado liso para evitar cortes o accidentes en la instalación.

Minoru

Minoru

Aldair

Elmer

Elmer

Elmer

Elmer

Milagros

Milagros

Milagros

Milagros

Isabell

Isabell

Isabell

USO

MONTAJE

SOFTWARE

SEGURIDAD

ERGONOMÍA

FABRICACIÓN

CONTROL DE CALIDAD

29/04/2026

29/04/2026

29/04/2026

29/04/2026

29/04/2026

29/04/2026

29/04/2026

29/04/2026

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
El sistema debe operar de forma continua durante al menos 8 horas sin intervención del usuario, conforme a los requerimientos técnicos del proyecto.

El dispositivo opera correctamente en un rango de temperatura ambiente de 10 a 50°C y humedad relativa de 20% a 90%, condiciones registradas en aulas y oficinas en Lima Metropolitana. [5]

El dispositivo puede ser transportado entre espacios sin riesgo de daño a sus componentes, siempre que se mantenga en posición estable y protegido de impactos directos.

El sistema está diseñado para uso en espacios cerrados interiores de alta ocupación (aulas, oficinas)

El costo total del prototipo asciende a S/ 950, distribuidos en: S/ 80 para componentes electrónicos (ESP32-WROOM-32, sensores MQ-135 y DHT11, relay), S/ 40 para estructura física (protoboard, carcasa), S/ 30 para ventilador, y S/ 800 para mano de obra de ensamblaje, programación y pruebas.

La entrega del prototipo funcional está programada para la semana 12 del calendario académico, con validación experimental en aula durante la semana 13, conforme al cronograma del curso de Fundamentos de Diseño — UPCH 2026-1.

Los sensores MQ-135 y DHT11 son reemplazables de forma sencilla sin herramientas especializadas.

El mantenimiento del sistema no requiere personal altamente especializado, siendo realizable por los propios usuarios con instrucciones básicas.

Todos

Todos

Todos

Aldair

Aldair

Milagros

Isabell

Isabell

PLAZOS

COSTOS

TRANSPORTE

MANTENIMIENTO

E = Exigencia (requisito obligatorio) D = Deseo (característica deseable)

## REFERENCIAS BIBLIOGRÁFICAS

1. World Health Organization. WHO global air quality guidelines: particulate matter (PM2.5 and PM10), ozone, nitrogen dioxide, sulfur dioxide and carbon monoxide [Internet]. Ginebra: WHO; 2021 [citado 6 may 2026]. Disponible en: https://www.who.int/publications/i/item/9789240034228
2. Organización de las Naciones Unidas. Informe de los Objetivos de Desarrollo Sostenible: edición

## especial [Internet]. Nueva York: ONU; 2023 [citado 6 may 2026]. Disponible en: https://unstats.un.org/sdgs/report/2023/

3. ASHRAE. Ventilation for acceptable indoor air quality (Standard 62.1) [Internet]. Atlanta: ASHRAE;

## 2019 [citado 6 may 2026]. Disponible en: https://www.ashrae.org/technical-

resources/bookstore/standards-62-1-62-2 (https://www.ashrae.org/technical-resources/bookstore/standards-62-1-62-2)
4. Pressac Sensing. CO2, Humidity & Temperature Wireless Sensor [Internet]. Pressac; [citado 6 may

## 2026]. Disponible en: https://www.pressac.com/environment-sensors/co2-temperature-and-

humidity-sensors/ (https://www.pressac.com/environment-sensors/co2-temperature-and-humidity-sensors/)
5. Aosong Electronics. DHT11 Temperature & Humidity Sensor Datasheet [Internet]. Aosong; [citado 6 may 2026]. Disponible en: https://www.mouser.com/datasheet/2/758/DHT11-Technical-Data-Sheet-Translated-Version-1143054.pdf (https://www.mouser.com/datasheet/2/758/DHT11-Technical-Data-Sheet-Translated-Version-1143054.pdf)
6. Berglund B, Lindvall T, Schwela D. Guías para el Ruido Urbano [Internet]. Organización Mundial de

## la Salud; 1999 [citado 6 may 2026]. Disponible en:

https://ocw.unican.es/pluginfile.php/868/course/section/485/Guias%2520para%2520el%2520ruido%2520urbano.pdf (https://ocw.unican.es/pluginfile.php/868/course/section/485/Guias%2520para%2520el%2520ruido%2520urbano.pdf)
7. Armstrong World Industries. Classroom Acoustics and ANSI Standard S12.60 [Internet]. Armstrong;

## [citado 6 may 2026]. Disponible en:

https://www.armstrongceilings.com/commercial/en/articles/classroom-acoustics-ansi-standard.html

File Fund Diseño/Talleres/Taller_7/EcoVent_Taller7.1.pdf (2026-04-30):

# EcoVent

# Sistema de Ventilación Inteligente

# Taller 7 · Documentación Técnica · Equipo 13

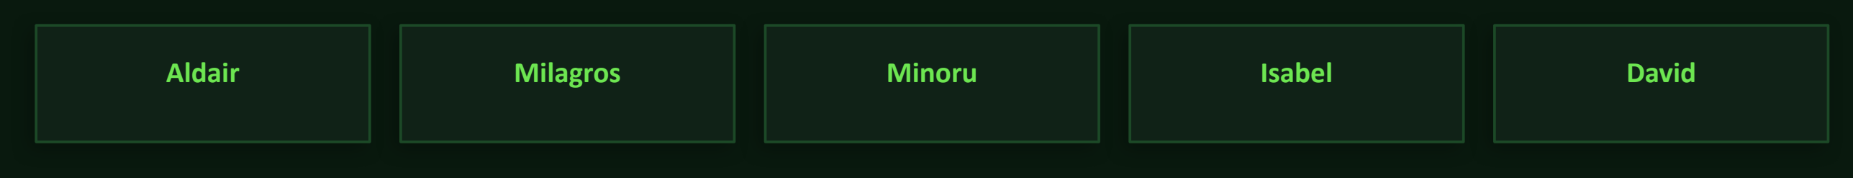
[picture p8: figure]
Aldair; Milagros; Minoru; Isabel; David

## Fundamentos de Diseño · 2026

# 3 Bocetos – Prototipo Eco-Vent

## Tres propuestas de diseño físico para modelado 3D en Onshape

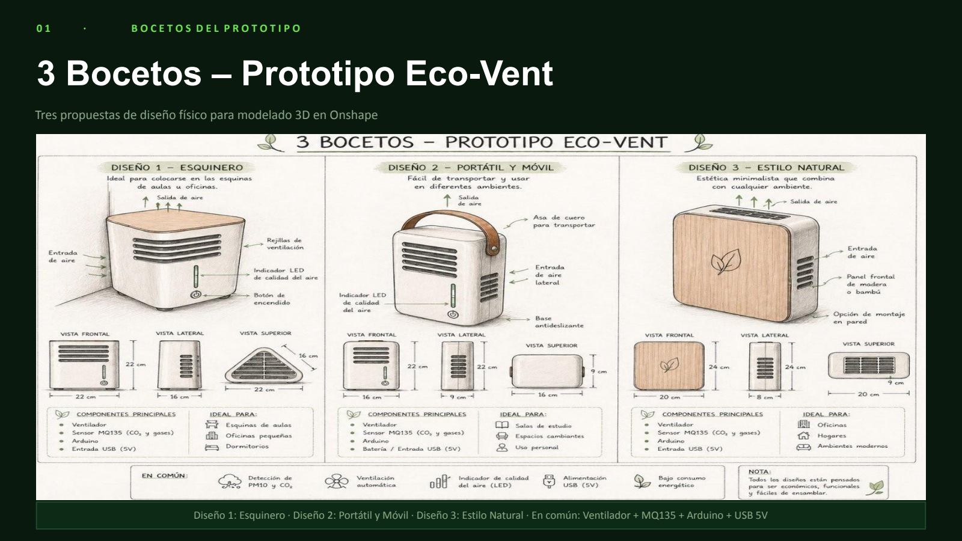
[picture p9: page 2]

0 1 | · | B O C E T O S D E L P R O T O T I P O

Diseño 1: Esquinero · Diseño 2: Portátil y Móvil · Diseño 3: Estilo Natural · En común: Ventilador + MQ135 + Arduino + USB 5V

# Caja Negra del Sistema Eco-Vent

## Flujo de Materia, Energía e Información

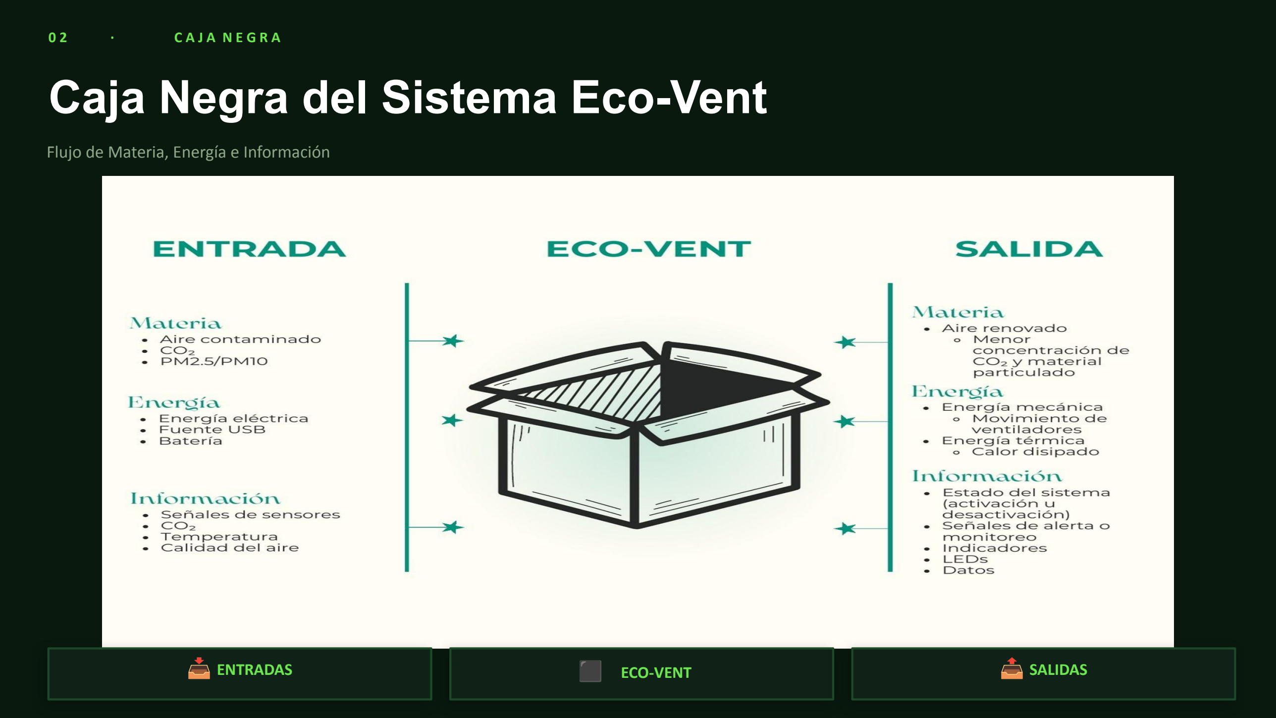
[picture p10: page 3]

0 2 | · | C A J A N E G R A
ENTRADAS | ⬛ ECO-VENT | SALIDAS

# Estructura de Funciones (Caja Blanca)

## 4 Dominios: Energía · Mecánico · Electrónico · Software

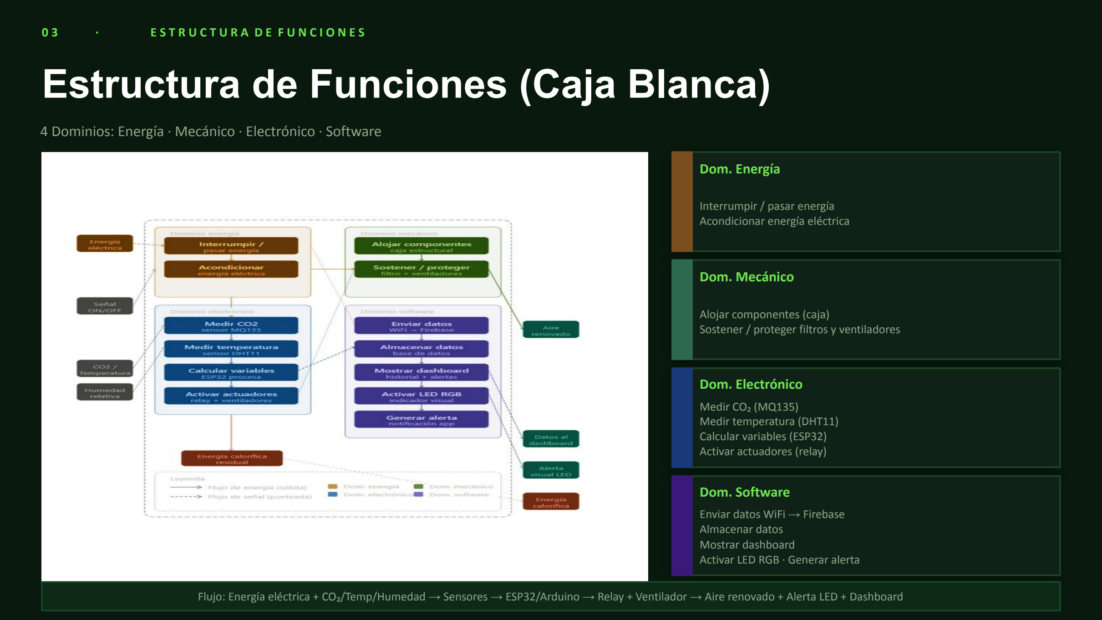
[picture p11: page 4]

0 3 | · | E S T R U C T U R A D E F U N C I O N E S

### Dom. Energía

Interrumpir / pasar energía Acondicionar energía eléctrica

### Dom. Mecánico

Alojar componentes (caja)
Sostener / proteger filtros y ventiladores

### Dom. Electrónico

Medir CO₂ (MQ135)
Medir temperatura (DHT11)
Calcular variables (ESP32) Activar actuadores (relay)

### Dom. Software

Enviar datos WiFi → Firebase Almacenar datos
Mostrar dashboard
Activar LED RGB · Generar alerta

Flujo: Energía eléctrica + CO₂/Temp/Humedad → Sensores → ESP32/Arduino → Relay + Ventilador → Aire renovado + Alerta LED + Dashboard

0 4 | · | L I S T A D E E X I G E N C I A S

# Lista de Exigencias

### - Rev 1.0 · 29/04/2026

E = Exigencia

D = Deseo

CATEG ORÍA | E/ D | DESCRIPCIÓN | RESPONSABLE
Función principal | E | Detectar CO₂ elevado y activar ventilación automáticamente sin intervención humana. | Todos
Geometría | E | Dimensiones máximas 200×150×80 mm. Fijación en superficies planas. | Minoru / Elmer
Fuerzas | E | Peso total inferior a 0.5 kg (carcasa + sensores + ventilador). | Minoru
Energía | E | Opera con 5V DC (USB estándar / powerbank). Consumo < 3 W continuo. | Elmer / Minoru
Energía | D | Puede operar con panel solar fotovoltaico de pequeña escala. | Aldair
Señales (E) | E | Entradas: señal MQ-135 (CO₂ ppm) y DHT11 (temp °C + humedad %). Salida: control relay. | Isabell / Elmer
Señales (D) | D | Visualización de datos en pantalla LCD/OLED en tiempo real. | Isabell
Hardware | E | Arduino UNO procesa señales. Relay soporta mínimo 10 A a 250 VAC. | Elmer / Minoru
Software | E | Algoritmo compara lectura con umbral 1 000 ppm CO₂ y activa ventilador. | Isabell
Seguridad | E | Sin riesgo eléctrico. Componentes HV aislados. Ruido < 45 dB. | Milagros
Ergonomía | E | Operación completamente autónoma, sin intervención del usuario. | Milagros
Fabricación | E | Componentes accesibles en mercado local peruano. Costo ≤ S/ 150. | Milagros / Todos
Uso | E | Opera en 0–50 °C, 20–90 % HR. Espacios hasta 40 personas. | Aldair
Mantenimiento | E | Sensores reemplazables sin herramientas. Calibración MQ-135 cada 6 meses (D). | Isabell
Plazos | E | Prototipo funcional: semana 12. Validación en aula: semana 13. | Todos

# Gracias

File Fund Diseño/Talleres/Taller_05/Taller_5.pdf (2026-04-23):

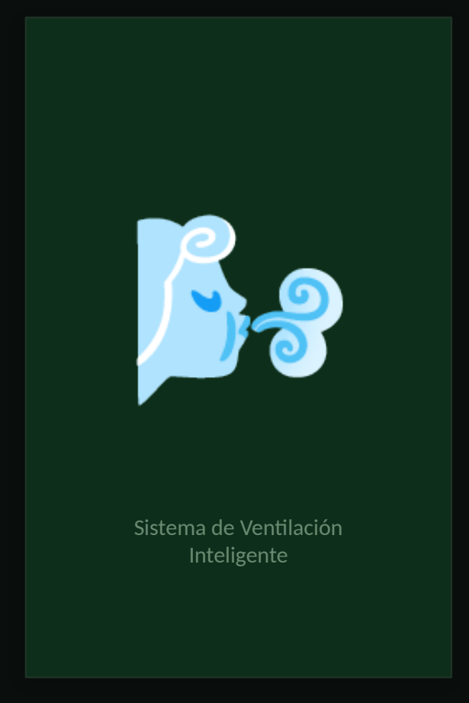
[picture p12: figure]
Sistema de Ventilación Inteligente

0 1 | · | H I S T O R I A

# ¿Cuándo fue la última vez que respiraste bien?

En un aula cerrada, en 40 minutos el CO2 sube a niveles que afectan la concentración. Nadie lo nota. Nadie actúa.

0 2 | · | P R O B L E M A

# El aire en espacios cerrados nos afecta sin que lo veamos

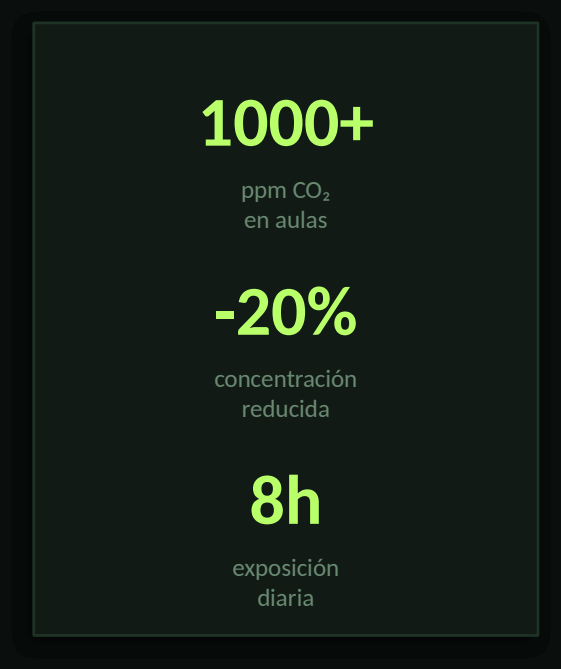
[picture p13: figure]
ppm CO₂ en aulas -20%; concentración reducida 8h; exposición diaria

🔴 Acumulación silenciosa de CO₂ y contaminantes en el aire

🔴 Fatiga, dolor de cabeza y pérdida de concentración

🔴 La ventilación depende de que alguien recuerde abrirla

🔴 Sin monitoreo continuo, no hay reacción a tiempo

# Eco-Vent — Sistema Inteligente

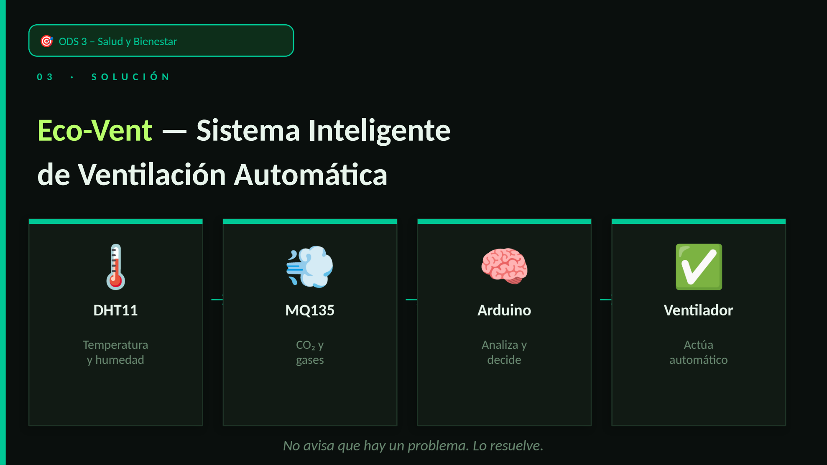
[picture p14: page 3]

🎯 ODS 3 – Salud y Bienestar

0 3 | · | S O L U C I Ó N

# de Ventilación Automática

🌡️

### DHT11

Temperatura
y humedad

→

💨

MQ135

CO₂ y
gases

→

🧠

### Arduino

Analiza y
decide

→

✅

### Ventilador

Actúa
automático

No avisa que hay un problema. Lo resuelve.

# ¿Quién lo necesita?

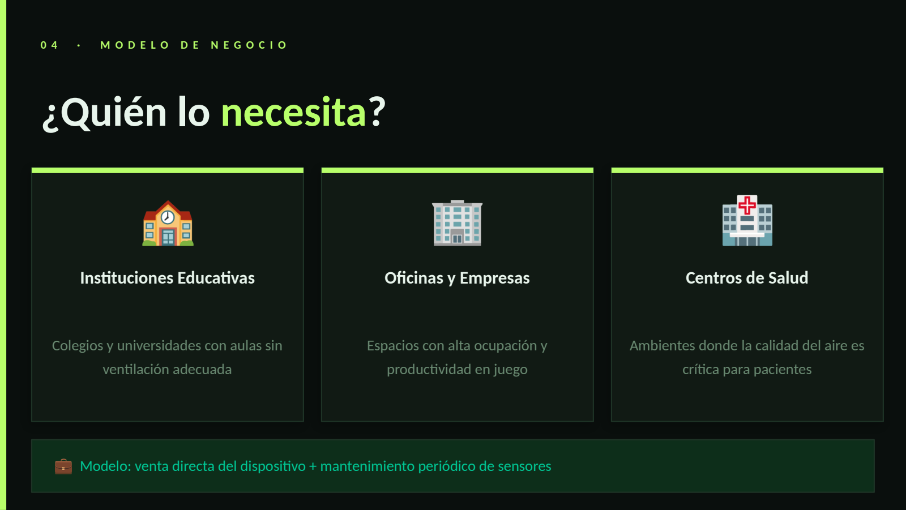
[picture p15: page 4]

0 4 | · | M O D E L O D E N E G O C I O

🏫

### Instituciones Educativas

Colegios y universidades con aulas sin ventilación adecuada

🏢

### Oficinas y Empresas

Espacios con alta ocupación y productividad en juego

🏥

### Centros de Salud

Ambientes donde la calidad del aire es crítica para pacientes

💼 Modelo: venta directa del dispositivo + mantenimiento periódico de sensores

# De prototipo a solución real

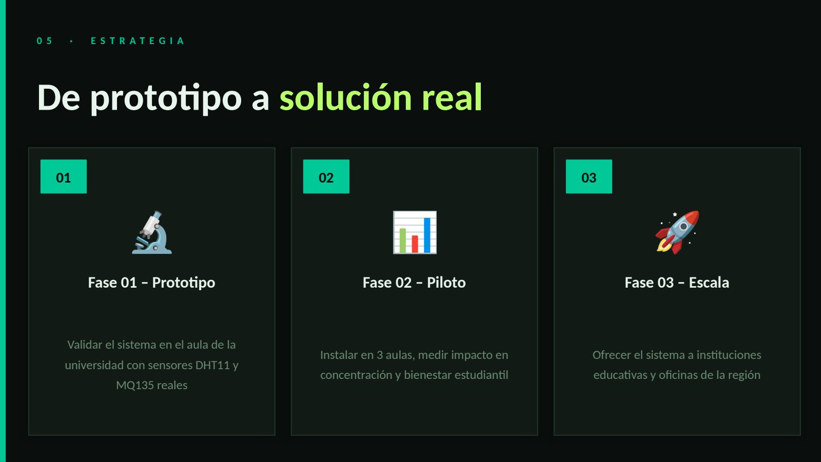
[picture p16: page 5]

0 5 | · | E S T R A T E G I A

01
🔬

### Fase 01 – Prototipo

Validar el sistema en el aula de la universidad con sensores DHT11 y MQ135 reales

02
📊

### Fase 02 – Piloto

Instalar en 3 aulas, medir impacto en concentración y bienestar estudiantil

03
🚀

### Fase 03 – Escala

Ofrecer el sistema a instituciones educativas y oficinas de la región

# ¿Qué hemos hecho ya?

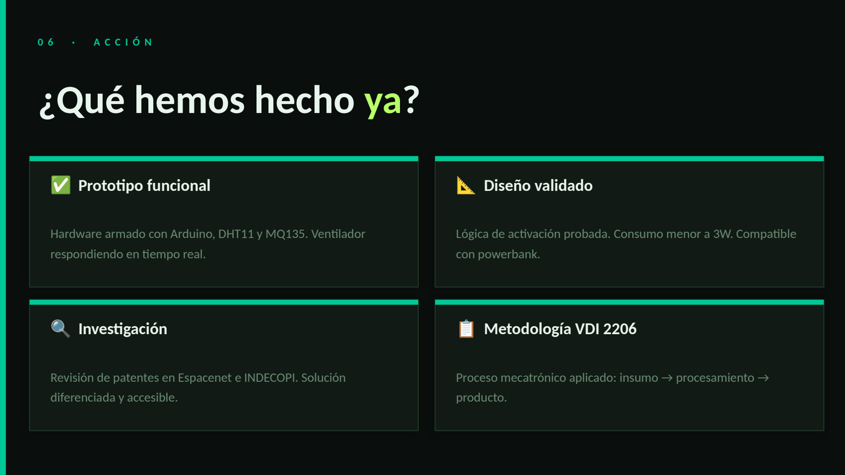
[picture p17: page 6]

0 6 | · | A C C I Ó N

### ✅ Prototipo funcional

Hardware armado con Arduino, DHT11 y MQ135. Ventilador respondiendo en tiempo real.

### 📐 Diseño validado

Lógica de activación probada. Consumo menor a 3W. Compatible con powerbank.

### 🔍 Investigación

Revisión de patentes en Espacenet e INDECOPI. Solución diferenciada y accesible.

### 📋 Metodología VDI 2206

Proceso mecatrónico aplicado: insumo → procesamiento → producto.

# Las personas detrás de Eco-Vent

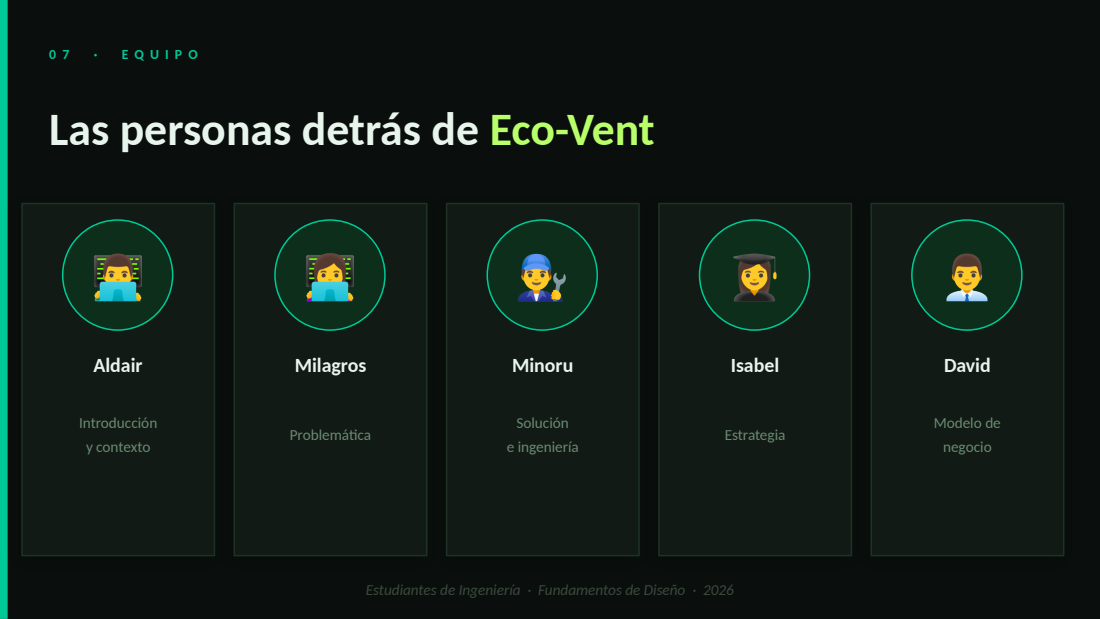
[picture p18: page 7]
Aldair; Introducción y contexto; Milagros; Problemática; Minoru; Solución e ingeniería; Isabel; Estrategia; David; Modelo de negocio

Estudiantes de Ingeniería · Fundamentos de Diseño · 2026

# Lo que pedimos

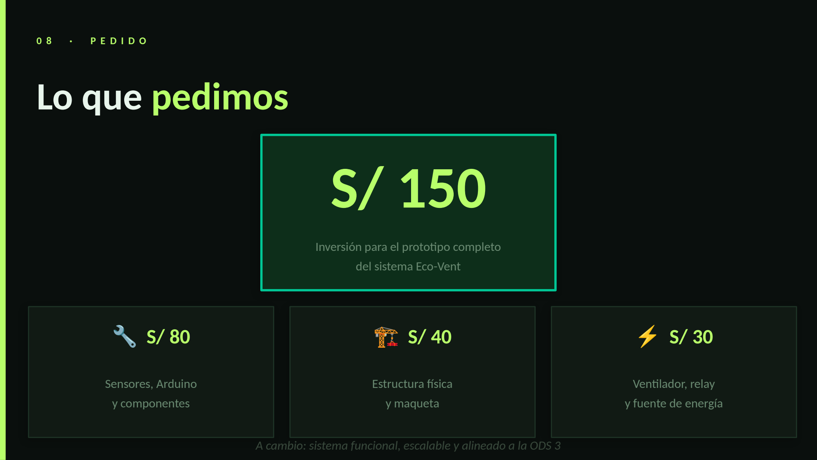
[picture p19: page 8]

0 8 | · | P E D I D O
S/ 150

Inversión para el prototipo completo del sistema Eco-Vent

🔧 S/ 80

Sensores, Arduino
y componentes

🏗️ S/ 40

Estructura física
y maqueta

⚡ S/ 30

Ventilador, relay
y fuente de energía

A cambio: sistema funcional, escalable y alineado a la ODS 3

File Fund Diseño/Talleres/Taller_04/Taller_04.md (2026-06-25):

# Taller 4: Búsqueda del Patentes

## 1. Introducción
En esta sesión se realizó la vigilancia tecnológica para identificar soluciones existentes en el monitoreo y gestión de la calidad del aire interior. Nuestro objetivo es asegurar que nuestra propuesta aporte un valor agregado y no duplique tecnologías ya patentadas.

## 2. Registro de Patentes Encontradas
### Patente 1 ⎯ Monitoreo de Renovación de Aire
- **Título:** Sistemas, dispositivos y métodos para el monitoreo del aire interior.
- **N° de Publicación:** US2023107402A1
- **Fecha de Publicación:** 06/04/2023
- **Solicitante / Inventor:** GOOD ROBOT MONITORING INC [CA]
- **Resumen:** Sistema que utiliza sensores de CO2 y partículas para determinar la tasa de renovación del aire y el riesgo de infección por vía aérea basándose en la ocupación en tiempo real.
- **Enlace:** [Espacenet - US2023107402A1](https://worldwide.espacenet.com/publicationDetails/biblio?FT=D&CC=US&NR=2023107402A1)
<div align="center">
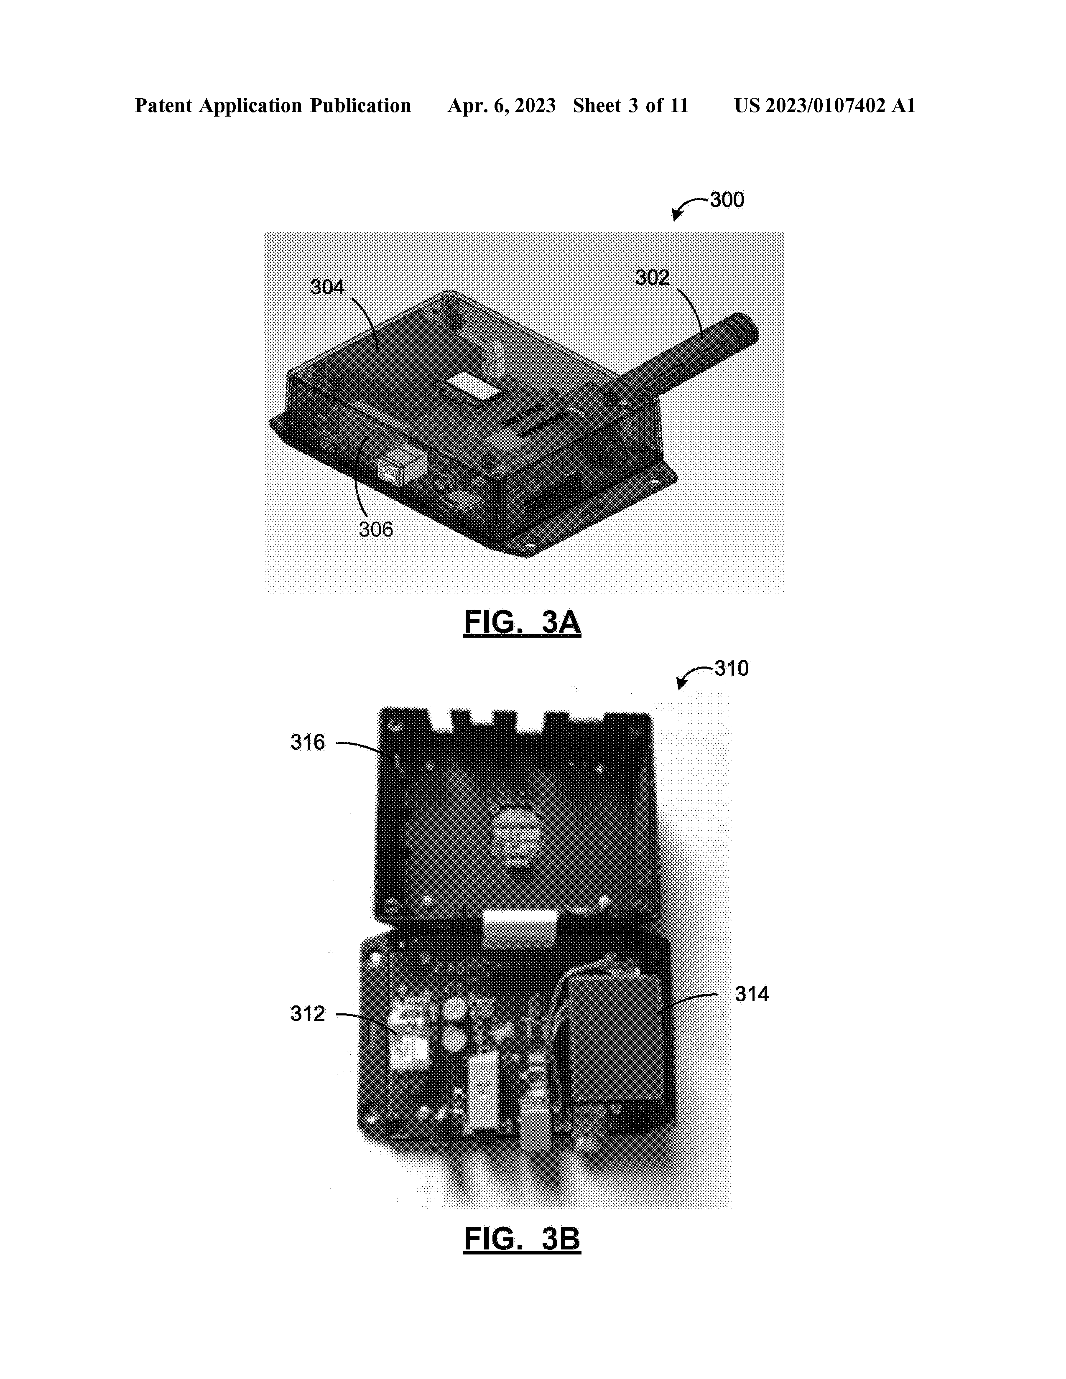
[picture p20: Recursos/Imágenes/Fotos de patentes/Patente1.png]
Patente 1
  
  <p><i>Figura 1</i></p>
</div>

### Patente 2 ⎯ Detección por Redes Neuronales
- **Título:** Método, sistema y dispositivo inteligente para la detección e identificación de la calidad del aire en el hogar, basado en una red neuronal artificial mejorada.
- **N° de Publicación:** CN120336783A
- **Fecha de Publicación:** 18/07/2025
- **Solicitante / Inventor:** Instituto de Tecnología de Nanjing.
- **Resumen:** Dispositivo basado en la plataforma STM32 e IoT que utiliza algoritmos de redes neuronales (FNN) para clasificar y reconocer contaminantes, temperatura y presión en hogares inteligentes.
- **Enlace:** [Espacenet - CN120336783A](https://worldwide.espacenet.com/publicationDetails/biblio?FT=D&CC=CN&NR=120336783A)
<div align="center">
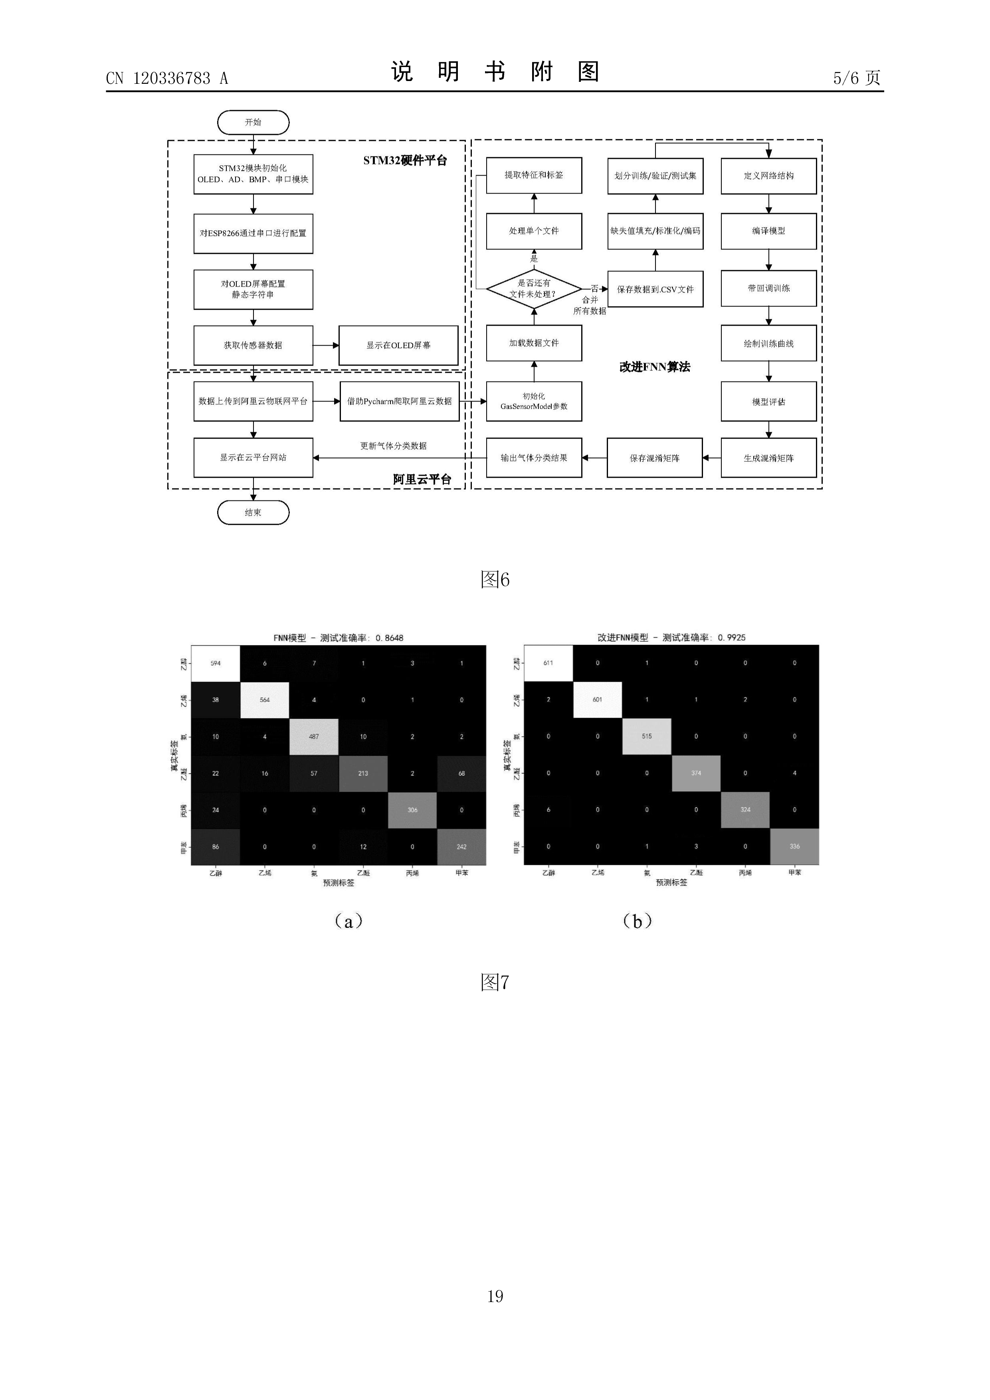
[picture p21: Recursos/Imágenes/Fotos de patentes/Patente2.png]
Patente 2
  
  <p><i>Figura 2</i></p>
</div>

### Patente 3 ⎯ Gestión de Aire con IA/ML
- **Título:** Un sistema y método para la gestión de la calidad del aire.
- **N° de Publicación:** WO2025141592A1
- **Fecha de Publicación:** 03/07/2025
- **Solicitante / Inventor:** HAMID YOUSUF HUSAINY [EN]
- **Resumen:** Sistema de gestión para edificios que utiliza IoT y módulos de Inteligencia Artificial/Machine Learning para predecir la calidad del aire y optimizar el consumo de energía en unidades de tratamiento de aire.
- **Enlace:** [Espacenet - WO2025141592A1](https://worldwide.espacenet.com/publicationDetails/biblio?FT=D&CC=WO&NR=2025141592A1)
<div align="center">
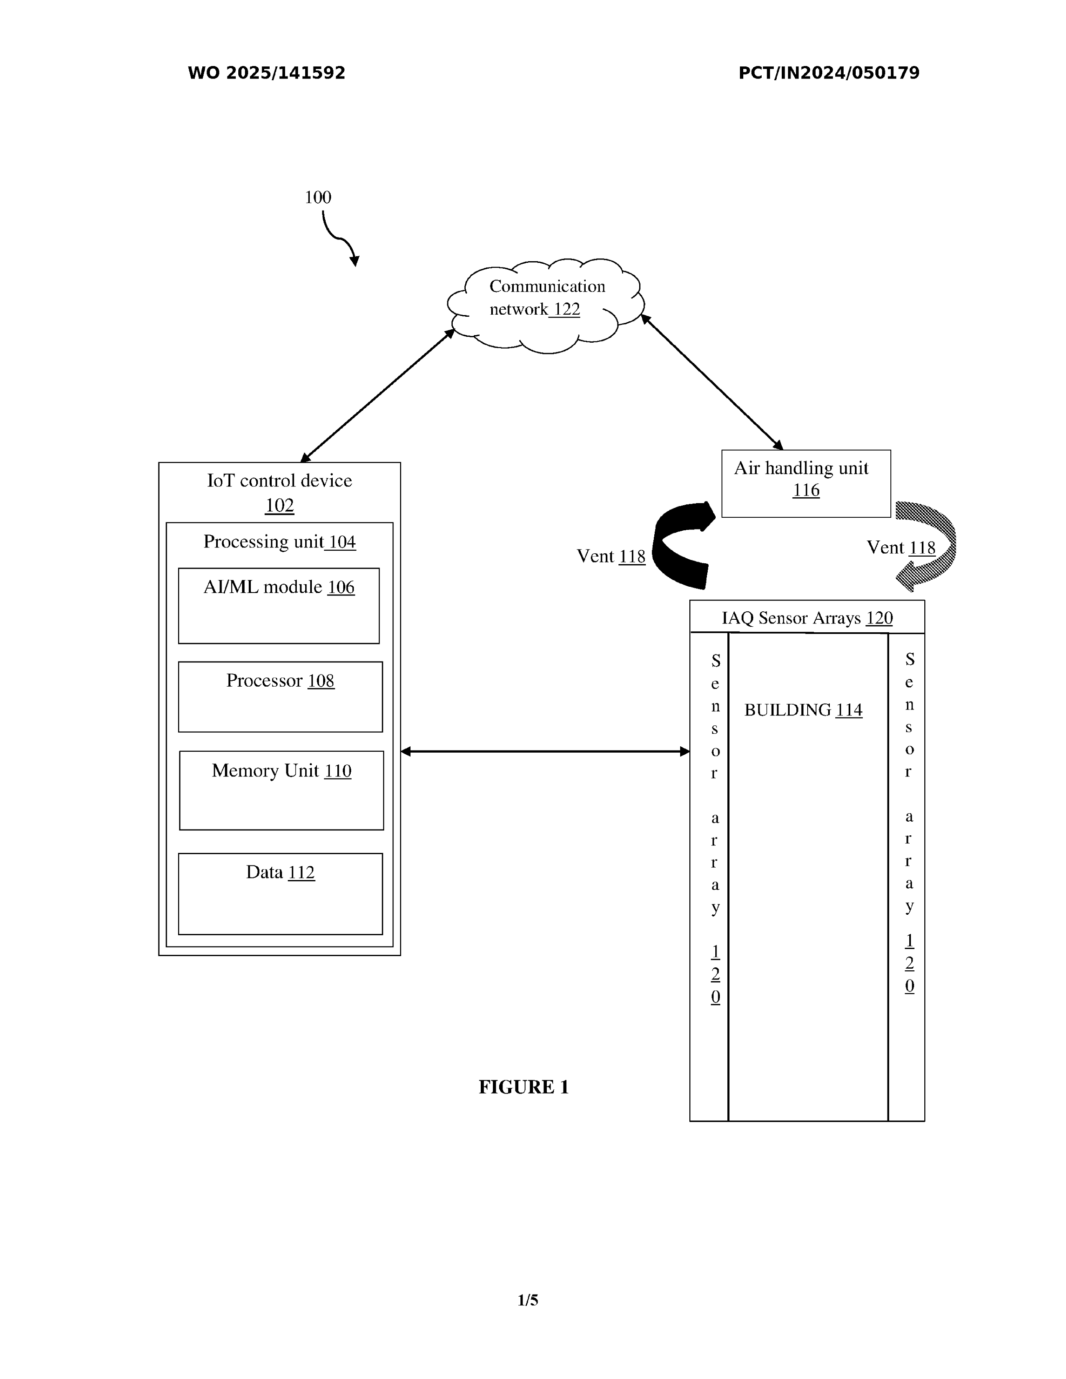
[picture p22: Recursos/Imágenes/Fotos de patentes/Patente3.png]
Patente 3
  
  <p><i>Figura 3</i></p>
</div>

## 3. Análisis de Innovación
Tras el análisis de las patentes US2023107402A1, CN120336783A y WO2025141592A1,hemos identificado los siguientes vacíos críticos y tecnológicos que nuestra propuesta planea cubrir

1. **Gestión Mixta**
   - Mientras las patentes internacionales se centran casi exclusivamente en el CO2 y la temperatura, nuestra propuesta reconoce que en el contexto peruano, el "aire pesado" incluye una carga significativa de **material particulado**. Nuestro sistema no solo busca mover aire viciado, sino gestionar flujos en entornos donde la ventilación pasiva es insuficiente para remover contaminantes densos.

2. **Acción Mecánica Directa de Bajo Consumo:**
   - Detectamos un vacío en la transición de la "lectura" a la "acción". Las soluciones existentes, como en las Patentes 1 y 2, suelen ser sistemas de monitoreo pasivo. Nuestro prototipo radica en la **acción inmediata** con el uso de actuadores de bajo consumo que ejecutan la ventilación de manera autónoma. Esto es vital en entornos donde el usuario sufre fatiga o saturación sensorial y no puede gestionar la ventilación de forma manual.

3. **Democratización Tecnológica y Sostenibilidad:**
   - A diferencia de la Patente 3, que requiere infraestructuras complejas de edificios inteligentes y módulos de IA/ML de alto costo, nuestro diseño bajo la metodología **VDI 2206** prioriza la accesibilidad. Al ser un sistema de bajo nivel, permite su implementación en nichos desatendidos como aulas de instituciones públicas, unidades de transporte, entornos laborales; garantizando el cumplimiento de las normas de seguridad y salud en los distintos ámbitos de aplicación.

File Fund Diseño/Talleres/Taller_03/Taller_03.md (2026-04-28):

## 1. Introducción
El diseño del sistema **Eco-Vent** responde a la crítica situación de la calidad del aire en Lima Metropolitana, donde los niveles de material particulado (PM10 y PM2.5) superan frecuentemente los límites recomendados. La investigación demuestra que en espacios educativos con ventilación natural deficiente, la acumulación de CO2 impacta directamente en la capacidad de toma de decisiones y atención de los estudiantes. Considerando que la infraestructura educativa actual en distritos como San Antonio requiere intervenciones urgentes para alcanzar el confort térmico, nuestro proyecto integra sensores de alta precisión siguiendo los protocolos de ASHRAE para garantizar un entorno de aprendizaje seguro y productivo.

---

## 2. Referencias Bibliográficas

### I. Estándares Internacionales y Objetivos Globales
1. Organización de las Naciones Unidas. Informe de los Objetivos de Desarrollo Sostenible: edición especial [Internet]. Nueva York: ONU; 2023 [citado 2026 Abr 8]. Disponible en: https://unstats.un.org/sdgs/report/2023/
2. World Health Organization. WHO global air quality guidelines: particulate matter (PM2.5 and PM10), ozone, nitrogen dioxide, sulfur dioxide and carbon monoxide [Internet]. Ginebra: WHO; 2021 [citado 2026 Abr 8]. Disponible en: https://www.who.int/publications/i/item/9789240034228
3. ASHRAE. Ventilation for acceptable indoor air quality (Standard 62.1) [Internet]. Atlanta: ASHRAE; 2019 [citado 2026 Abr 8]. Disponible en: https://www.ashrae.org/technical-resources/bookstore/standards-62-1-62-2
4. United States Environmental Protection Agency. Indoor Air Quality (IAQ) [Internet]. Washington D.C.: EPA; 2023 [citado 2026 Abr 8]. Disponible en: https://www.epa.gov/indoor-air-quality-iaq
5. European Environment Agency. Air quality in Europe — 2022 report [Internet]. Copenhague: EEA; 2022 [citado 2026 Abr 8]. Disponible en: https://www.eea.europa.eu/publications/air-quality-in-europe-2022

### II. Realidad Nacional y Calidad del Aire en Perú
6. Valdivia SAP. Análisis temporal y espacial de la calidad del aire determinado por material particulado PM10 y PM2,5 en Lima Metropolitana. Anales Científicos [Internet]. 2016 [citado 2026 Abr 28];77(2):273-283. Disponible en: https://dialnet.unirioja.es/servlet/articulo?codigo=6171218
7. Aguirre Bellido D, Chacón García RH. Monitoreo de calidad del aire en las inmediaciones de la Planta de Cementos Lima SAA en el distrito de Villa María del Triunfo [Internet]. Lima: OEFA; 2014 [citado 2026 Abr 28].
8. Huerta AJD. Confort térmico a través de las estrategias de ventilación natural de espacios en instituciones educativas en San Antonio [Internet]. Lima: Universidad César Vallejo; 2018 [citado 2026 Abr 28]. Disponible en: https://alicia.concytec.gob.pe/vufind/Record/UCVV_1df5dbf063920edf83a42bb91044ba7b
9. Rojas FJ, Pacsi-Valdivia S, Sánchez-Ccoyllo OR. Simulación computacional e influencia de las variables meteorológicas en las concentraciones de PM10 y PM2.5 en Lima Metropolitana. Información tecnológica [Internet]. 2022 [citado 2026 Abr 28];33(3):223-238. Disponible en: https://www.scielo.cl/scielo.php?pid=S0718-07642022000300223&script=sci_arttext&tlng=en
10. Oropeza Tello HA, Díez Chirinos CMS. Análisis de información satelital para el estudio de la calidad del aire: caso de estudio Lima, Perú [Internet]. Lima: UTEC; 2022 [citado 2026 Abr 28]. Disponible en: https://agris.fao.org/search/en/providers/125040/records/674978937625988a37221ae5

### III. Impacto en la Salud y el Rendimiento Académico
11. Satish U, Mendel MJ, Shekhar K, Hotchi T, Sullivan D, Streufert S, et al. Is CO2 an Indoor Pollutant? Direct Effects of Low-to-Moderate CO2 Concentrations on Human Decision-Making Performance. Environ Health Perspect [Internet]. 2012 [citado 2026 Abr 28];120(12). Disponible en: https://pmc.ncbi.nlm.nih.gov/articles/PMC3546345/
12. Bakó-Biró Z, Clements-Croome DJ, Kochhar N, Awbi HB, Williams MJ. Ventilation rates in schools and pupils’ performance. Build Environ [Internet]. 2012 [citado 2026 Abr 28];48:215-223. Disponible en: https://www.sciencedirect.com/science/article/abs/pii/S0360132311002617?via%3Dihub
13. Coley DA, Greeves R, Saxby BK. The effect of low ventilation rates on the cognitive function of a primary school class. Int J Vent [Internet]. 2007 [citado 2026 Abr 28];6(2):107-112. Disponible en: https://doi.org/10.1080/14733315.2007.11683770
14. Diaz M, Cools M, Trebilcock M, Piderit-Moreno B, Attia S. Effects of climatic conditions, season and environmental factors on CO2 concentrations in naturally ventilated primary schools in Chile. Sustainability [Internet]. 2021 [citado 2026 Abr 28];13(8):4139. Disponible en: https://www.mdpi.com/2071-1050/13/8/4139
15. Alexander TZ, Rivera Poma JM. Evaluación del confort térmico en aulas y oficinas de la Facultad de Ingeniería Industrial de la UNMSM [Tesis en Internet]. Lima: Universidad Nacional Mayor de San Marcos; 2022 [citado 2026 Abr 28]. Disponible en: https://industrial.unmsm.edu.pe/investigacionfii/wp-content/uploads/2021/07/07.-TI-EPISST-TINEO-ZAMORA.pdf
16. Johnson DL, Lynch RA, Floyd EL, Wang J, Bartels JN. Indoor air quality in classrooms: Environmental measures and effective ventilation rate modeling in urban elementary schools. Build Environ [Internet]. 2018 [citado 2026 Abr 28];136:185-197. Disponible en: https://doi.org/10.1016/j.buildenv.2018.03.040

### IV. Especificaciones Técnicas e Informes de Control
17. Arduino. Arduino Documentation Reference [Internet]. 2024 [citado 2026 Abr 8]. Disponible en: https://www.arduino.cc/reference/en/
18. Organismo de Evaluación y Fiscalización Ambiental. Evaluación Ambiental de Causalidad en la Planta Pomalca (Informe N° 00180-2023-OEFA) [Internet]. Lima: OEFA; 2023 [citado 2026 Abr 28]. Disponible en: https://repositorio.oefa.gob.pe/items/8f5525af-dd99-4b53-bb9c-635a1b3a9b2c

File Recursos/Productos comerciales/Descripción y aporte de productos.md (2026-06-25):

# Productos Comerciales

## Descripción

En esta sección se presentan los productos comerciales analizados durante el desarrollo del proyecto **Eco-Vent**. Estos dispositivos fueron seleccionados debido a que incorporan tecnologías de monitoreo ambiental, ventilación mecánica automatizada y control basado en la calidad del aire interior. Más que ser considerados competidores directos, fueron estudiados como referentes tecnológicos consolidados que permitieron contrastar decisiones de diseño, identificar buenas prácticas de ingeniería y validar criterios funcionales aplicados en el desarrollo del prototipo.

---

# Producto 1

## BROAD Fresh Air – AirPro Car Plus (FC-2 / FC-3)

### Descripción

El BROAD AirPro Car Plus es un purificador portátil diseñado para espacios cerrados que integra monitoreo continuo de dióxido de carbono (CO₂), visualización directa de datos ambientales y mecanismos de ventilación y filtrado de aire. El dispositivo incorpora una pantalla digital para la lectura de concentraciones de CO₂ en tiempo real, alertas automáticas cuando la calidad del aire disminuye y múltiples niveles de funcionamiento adaptados a la demanda del entorno.

### Aporte al Proyecto

* Sirvió como referencia para la incorporación del monitoreo continuo de CO₂ como una de las variables principales supervisadas por Eco-Vent.

* Reforzó la importancia de presentar información ambiental mediante indicadores comprensibles para usuarios sin conocimientos especializados en electrónica o programación.

* Proporcionó criterios de diseño relacionados con la operación autónoma del sistema, permitiendo que las respuestas de ventilación dependan de las condiciones reales del ambiente.

* Evidenció la viabilidad de integrar funciones de monitoreo y ventilación dentro de una solución compacta y de bajo consumo energético.

* Inspiró la adopción de una filosofía de diseño orientada a la accesibilidad, simplicidad de uso y consulta rápida del estado de la calidad del aire.

🔖 Ver brochure: https://broadfreshair.com/products/airpro-car-co2-sensor?variant=36442260209817

---

# Producto 2

## Aereco VMX – Sistema de Ventilación Controlada por Demanda

### Descripción

El sistema Aereco VMX implementa una estrategia de Ventilación Controlada por Demanda (DCV), en la cual la renovación del aire depende directamente de las condiciones reales de ocupación y calidad ambiental del recinto. Mediante sensores de CO₂ y otras variables ambientales, el sistema ajusta automáticamente el caudal de ventilación, incrementando o reduciendo su funcionamiento según las necesidades detectadas.

### Aporte al Proyecto

* Sirvió como referencia para la implementación de una estrategia de ventilación basada en la demanda real del ambiente en lugar de una operación permanente de los ventiladores.

* Respaldó el uso de la concentración de CO₂ como variable de decisión para activar procesos de renovación de aire en espacios cerrados de alta ocupación.

* Proporcionó criterios para la definición de umbrales de actuación y reglas de control orientadas a preservar la calidad del aire interior.

* Evidenció los beneficios energéticos asociados a la ventilación controlada por demanda, aspecto que se encuentra alineado con los objetivos de eficiencia energética de Eco-Vent.

* Reforzó la importancia de desarrollar un sistema capaz de operar de manera autónoma, reduciendo la necesidad de intervención manual por parte del usuario.

🔖 Ver brochure: https://www.aereco.com/products/non-residential-systems/vmx-system/

---

# Producto 3

## Blauberg Vento Expert A50-1 W (V.3)

### Descripción

El Blauberg Vento Expert A50-1 W es una unidad compacta de ventilación mecánica diseñada para la renovación continua del aire en espacios interiores. Su arquitectura integra ventilación activa, operación silenciosa y mecanismos orientados a la eficiencia energética, permitiendo mantener condiciones ambientales adecuadas dentro de habitaciones y espacios cerrados de ocupación variable.

### Aporte al Proyecto

* Sirvió como referencia para el diseño conceptual de una solución de ventilación mecánica compacta orientada a espacios cerrados de uso cotidiano.

* Proporcionó criterios relacionados con la renovación activa del aire mediante procesos controlados de extracción e ingreso de aire fresco.

* Evidenció la importancia de considerar la eficiencia energética durante la selección y operación de los sistemas de ventilación.

* Reforzó la necesidad de minimizar el impacto acústico del dispositivo para garantizar su utilización en entornos educativos, oficinas y espacios de trabajo.

* Ayudó a validar la viabilidad de implementar una solución autónoma de ventilación local que pueda instalarse sin modificaciones complejas en la infraestructura existente.

🔖 Ver brochure: https://blauberg-na.com/series/vento-expert-a50-1-w-v2/

---

## Consideraciones de Diseño

1. Los productos analizados fueron utilizados como referentes tecnológicos y no como competidores directos del proyecto.

2. El análisis se enfocó en identificar principios de funcionamiento, estrategias de control y criterios de diseño aplicables a una solución académica de menor escala y costo accesible.

3. Los aportes identificados permitieron respaldar decisiones relacionadas con el monitoreo de CO₂, la ventilación por demanda, la automatización del sistema y la eficiencia energética del prototipo Eco-Vent.

4. La información obtenida fue empleada para fortalecer el proceso de diseño conceptual, la definición de funcionalidades y la justificación técnica de las decisiones adoptadas durante el desarrollo del proyecto.

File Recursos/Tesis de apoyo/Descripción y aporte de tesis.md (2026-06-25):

# Tesis

## Descripción

En esta sección se detallan las tesis de repositorio nacionales e internacionales consultadas como antecedentes metodológicos, metrológicos y de ingeniería para el desarrollo del proyecto **Eco-Vent 13**. Estos trabajos proporcionan las líneas base sobre el comportamiento de variables higrotérmicas y de concentración de gases, convalidando de manera analítica el dimensionamiento del hardware, el diseño modular y la transición hacia una lógica de control activo automatizado.

---

# Tesis 1: Confort térmico a través de las estrategias de ventilación natural de espacios en instituciones educativas en San Antonio

* **Autor:** Huerta Ayn JD.

* **Año / Universidad:** 2021 | *Universidad César Vallejo (Tesis de licenciatura para optar el título profesional de Arquitecto).*

* **Descripción:**
  Investigación cualitativa y descriptiva con diseño fenomenológico que analizó las deficiencias de las estrategias pasivas y de ventilación natural en la infraestructura de las instituciones de enseñanza del distrito de San Antonio. El diagnóstico reveló que el 70% de los establecimientos a nivel nacional requieren de reestructuraciones profundas debido a la mala orientación del asoleamiento, la predominancia de pisos de cemento pulido que acumulan calor y la incapacidad del diseño arquitectónico tradicional para estabilizar la habitabilidad del aire por vías únicamente naturales.

* **Aporte directo al proyecto:**

  * **Justificación de Dispositivo Modular Autónomo:**
    Sustenta el dimensionamiento y la viabilidad de instalación de la carcasa vertical de nuestro prototipo (220 × 220 × 110 mm). Al demostrar que la infraestructura escolar local presenta deficiencias estructurales críticas que anulan la efectividad de la ventilación pasiva, se justifica el desarrollo de un dispositivo activo y autónomo de bajo costo que pueda fijarse directamente en paredes o techos sin requerir modificaciones arquitectónicas complejas ni sistemas HVAC centralizados de alto costo.

---

# Tesis 2: Evaluación del confort térmico en aulas y oficinas de la Facultad de Ingeniería Industrial de la Universidad Nacional Mayor de San Marcos

* **Autor:** Tineo Zamora A.

* **Año / Universidad:** 2021 | *Universidad Nacional Mayor de San Marcos (Trabajo de investigación para optar el grado académico de Bachiller en Ingeniería de Seguridad y Salud en el Trabajo).*

* **Descripción:**
  La investigación evaluó de manera objetiva el confort térmico en ambientes de alta ocupación universitaria durante la estación de verano utilizando el método de Fanger. El estudio determinó de forma cuantitativa que los espacios superan drásticamente el porcentaje estimado de insatisfechos (PPD) debido a que el calor radiante excede los 27 °C, considerado el valor máximo de tolerancia térmica y umbral de estrés térmico en la costa peruana según la escala de ASHRAE.

* **Aporte directo al proyecto:**

  * **Calibración de Umbrales Físicos:**
    Proporciona la justificación científica para el procesamiento lógico de las variables de temperatura en nuestro software. Al demostrar que los entornos universitarios locales sin climatización activa superan con facilidad los 27 °C en temporada cálida generando estrés térmico, valida técnicamente que el microcontrolador central de Eco-Vent deba evaluar de forma síncrona los datos de las variables higrotérmicas para activar la actuación mecánica forzada por demanda cuando se alcance este límite físico exacto.

---

# Tesis 3: Diseño e implementación de un prototipo basado en IoT de un sistema de control para la producción de orégano en invernadero, en el distrito La Yarada Los Palos 2024

* **Autor:** Portugal Cuno EA.

* **Año / Universidad:** 2025 | *Universidad Privada de Tacna (Tesis de pregrado para optar el título de Ingeniero Electrónico).*

* **Descripción:**
  Desarrollo de un prototipo automatizado para la monitorización de variables agrícolas (temperatura, humedad relativa, humedad del suelo, CO₂, pH y nivel de agua) en un entorno cerrado. El sistema emplea una red de comunicación local inalámbrica en estrella con módulos NRF24L01 conectados a nodos esclavos y un nodo central encargado del procesamiento de datos lógicos y su transmisión externa hacia la nube mediante tecnologías celulares.

* **Aporte directo al proyecto:**

  * **Validación de la Lógica Multivariable:**
    Esta investigación convalida de forma analítica e ingenieril el trinomio de monitorización y la especificación de restricciones de nuestro proyecto. Al demostrar que variables críticas como el CO₂ y las fluctuaciones térmicas interactúan dinámicamente influyendo en la calidad biológica del entorno cerrado, justifica que el firmware de un sistema mecatrónico deba leer y procesar de manera simultánea estos parámetros para tomar acciones de control automatizadas.

  * **Optimización de Mensajes y Tránsito de Datos:**
    El estudio provee un análisis matemático del balance y restricción de mensajes mensuales para la comunicación a servidores externos en la nube, demostrando cómo programar transmisiones intermitentes en intervalos discretos para optimizar el consumo de datos y evitar la saturación de los canales de comunicación serial.

---

# Tesis 4: Desarrollo de una cabina de control de variables ambientales para la fructificación y estado de maduración basado en procesamiento de imágenes de hongos macroscópicos comestibles aplicado al Hericium erinaceus

* **Autores:** Zegarra León LM & De La Flor Armas JA.

* **Año / Universidad:** 2025 | *Universidad Peruana de Ciencias Aplicadas (Trabajo de suficiencia profesional para optar el título de Ingeniero Mecatrónico).*

* **Descripción:**
  Diseño y construcción de una cabina automatizada equipada con módulos independientes de control ambiental (temperatura, humedad relativa y CO₂) bajo la lógica de un Arduino Mega 2560. Incorpora un sistema de visión artificial basado en una Raspberry Pi 4 y modelos neuronales YOLOv5 para identificar de forma automatizada las etapas fenológicas y de maduración del cultivo sin contacto físico.

* **Aporte directo al proyecto:**

  * **Justificación de la Unidad de Procesamiento Central:**
    Respalda directamente la viabilidad y robustez de utilizar el microcontrolador central como el cerebro del hardware. Debido a la gran cantidad de pines digitales y entradas analógicas requeridas por los sensores de gases y variables higrométricas, esta investigación demuestra que el procesamiento central proporciona la estabilidad de voltaje e inmunidad al ruido eléctrico necesarias para ejecutar la conmutación de actuadores de potencia sin comprometer la estabilidad del sistema.

  * **Discretización Algorítmica y Lógica de Control:**
    Detalla la implementación en código de controladores discretos y ecuaciones de histéresis asimétrica para la gestión de variables ambientales lentas o de alta inercia. Esto aporta el fundamento matemático para estructurar las rutinas de software, asegurando que las órdenes de encendido y apagado de los extractores mecánicos y ventiladores operen bajo márgenes rígidos de seguridad para prolongar la vida útil del hardware y proteger el circuito eléctrico.

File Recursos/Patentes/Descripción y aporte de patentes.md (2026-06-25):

# Patentes

## Descripción

En esta sección se detallan las patentes internacionales analizadas como la base de conocimiento técnico para el desarrollo de **Eco-Vent 13** bajo la metodología **VDI 2206**. El análisis cuantitativo de estos antecedentes mecánicos, electrónicos y de software convalidan el dimensionamiento de nuestro hardware y justifican el valor innovador de nuestro prototipo frente al estado de la técnica.

<p align="center">
  <a href="https://worldwide.espacenet.com/publicationDetails/biblio?FT=D&CC=US&NR=2023107402A1" target="_blank">
    
  </a>
  <a href="https://worldwide.espacenet.com/publicationDetails/biblio?FT=D&CC=CN&NR=120336783A" target="_blank">
    
  </a>
  <a href="https://worldwide.espacenet.com/publicationDetails/biblio?FT=D&CC=WO&NR=2025141592A1" target="_blank">
    
  </a>
</p>

---

# Patente 1

### Título
**US2023107402A1: Systems, devices, and methods for monitoring indoor air**
*Sistemas, dispositivos y métodos para el monitoreo del aire interior*

### Descripción
Patente internacional enfocada en la monitorización de espacios interiores mediante sensores de Dióxido de Carbono (CO₂) o partículas suspendidas conectados a un procesador y a una interfaz de comunicación. El sistema recibe datos continuos durante periodos extendidos (ocupados y desocupados), identifica regiones de interés con tasas constantes de decaimiento y calcula de forma automática la tasa de renovación de aire (ACH) y el riesgo de infección por aerosoles en tiempo real.

### Aporte directo al proyecto
* **Convalidación del Lazo de Control Lógico:** Valida de forma directa nuestro modelo de procesamiento matemático. La patente demuestra que analizar las curvas de decaimiento de gases cuando el ambiente se desocupa es el método metrológico idóneo para calcular la tasa de renovación de aire forzada, sirviendo como fundamento para el desarrollo de nuestros diagramas de flujo lógicos de control autónomo.

---

# Patente 2

### Título
**CN120336783A: 一种基于改进FNN的智能家居空气检测识别方法、系统、设备及存储介质**
*Método, sistema, dispositivo y medio de almacenamiento de detección e identificación de aire en el hogar inteligente basado en una red neuronal artificial (FNN) mejorada*

### Descripción
Patente orientada a la domótica que integra una plataforma de hardware empotrada basada en un microcontrolador STM32, un módulo de presión barométrica BMP280, un módulo de comunicación inalámbrica ESP8266 y una terna de sensores de gas (TGS2600, TGS2602, TGS2610 y TGS2620). El sistema realiza una extracción multicanal de 128 vectores de características (稳态特征 / 动态特征) y entrena una red neuronal prealimentada (FNN) optimizada con el algoritmo Adam y funciones de pérdida por entropía cruzada para clasificar contaminantes químicos con una precisión superior al 95%.

### Aporte directo al proyecto
* **Sustento de la Arquitectura de Hardware:** Valida la estructura electrónica integrada de Eco-Vent 13. Conconcluye que la recolección síncrona de variables termohigrométricas y químicas mediante sensores analógicos/digitales acoplados a un microcontrolador y un módulo Wi-Fi (ESP8266) es una arquitectura viable para identificar patrones de contaminación en tiempo real.
* **Criterio de Interfaz Local:** Respalda nuestro diseño de interfaz de usuario local al demostrar que el procesamiento directo en el hardware de bajo costo permite desplegar alertas inmediatas en una pantalla OLED local sin generar latencia ni depender de servidores externos en la etapa crítica de detección.

---

# Patente 3

### Título
**WO2025141592A1: A system and method for air quality management**
*Un sistema y método para la gestión de la calidad del aire*

### Descripción
Patente global que describe un sistema de purificación y acondicionamiento ambiental por demanda para edificaciones complejas. Implementa una red de arreglos de sensores de calidad de aire distribuidos en múltiples zonas (interiores y exteriores) conectados mediante IoT a un dispositivo de control central con un módulo de Inteligencia Artificial (AI/ML). El sistema procesa los datos mecánicos, térmicos y de contaminación para generar señales de comando que modulan de forma aislada las unidades de tratamiento de aire (Smart Air Handling Units - SAHU), optimizando el consumo energético del edificio ante episodios de contaminación aguda o variaciones del entorno.

### Aporte directo al proyecto
* **Justificación de la Actuación por Demanda:** Fundamenta la ventaja de ingeniería de Eco-Vent 13. Demuestra que para mitigar la recirculación de aire viciado es técnicamente necesario un sistema de actuación que module la inyección y extracción mecánica forzada de forma automatizada basándose en rangos preestablecidos, en lugar de mantener extractores fijos de alto consumo.
* **Diseño del Banco de Conmutación:** Respalda la inclusión electrónica de nuestro banco de relés independientes. La patente establece que cada zona o extractor axial requiere una gestión aislada de señales de potencia para equilibrar las presiones neumáticas y estabilizar las corrientes eléctricas del circuito, evitando paralelismos de corriente que afecten el microcontrolador central.

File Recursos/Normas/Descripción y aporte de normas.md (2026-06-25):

# 📜 Descripción y Aportes de Normas Técnicas — Equipo 13

En esta sección se presentan las normas técnicas y los marcos legales nacionales considerados durante el desarrollo del proyecto **Eco-Vent 13**. Estas normativas proporcionan los lineamientos jurídicos, los criterios de diseño ambiental y los estándares de medición necesarios para asegurar que nuestro sistema mecatrónico responda con rigor a las exigencias de salud pública y control atmosférico bajo la metodología VDI 2206.

<p align="center">
  <a href="https://www.gob.pe/institucion/minam/normas-legales/3670-003-2017-minam" target="_blank">
    
  </a>
  <a href="https://sinia.minam.gob.pe/normas/decreto-supremo-que-aprueba-protocolo-nacional-monitoreo-calidad" target="_blank">
    
  </a>
  <a href="https://www.gob.pe/institucion/congreso-de-la-republica/normas-legales/3569-28611" target="_blank">
    
  </a>
</p>

---

## Norma Técnica 1: Decreto Supremo N° 003-2017-MINAM — Estándares de Calidad Ambiental (ECA) para Aire

### Descripción
Esta norma legal dictada por el Ministerio del Ambiente del Perú establece las medidas concisas de las concentraciones de elementos, sustancias o parámetros físicos y químicos presentes en el aire en su condición de cuerpo receptor. Su propósito es regular los límites máximos destinados a prevenir y resguardar la salud pública, fijando el umbral diario para el Material Particulado con diámetro menor a 10 micras en 100 microgramos por metro cúbico durante un periodo de 24 horas.

### Aporte al proyecto
* **Sustento de Umbrales Ambientales:** Proporciona el marco de referencia legal para justificar el diseño de los filtros mecánicos del dispositivo. Al contrastar estos límites obligatorios con los reportes históricos de saturación en zonas de alta densidad vehicular e industrial de Lima, se convalida técnicamente la necesidad de implementar un sistema cerrado de inyección y extracción forzada capaz de mitigar la exposición crónica a partículas sólidas gruesas.

---

## Norma Técnica 2: Decreto Supremo N° 010-2019-MINAM — Protocolo Nacional de Monitoreo de la Calidad Ambiental del Aire

### Descripción
Este decreto supremo aprueba las disposiciones técnicas y metodológicas estandarizadas para realizar las operaciones de muestreo, medición analítica y aseguramiento de la calidad de los datos de las variables atmosféricas en el territorio nacional. Regula la representatividad de las muestras, los tiempos mínimos de captura de información y los criterios metrológicos para garantizar la validez de los registros de agentes químicos y físicos.

### Aporte al proyecto
* **Validación Metrológica del Firmware:** Convalida la lógica de programación del bucle de control implementado en el microcontrolador. La norma exige que la captura de datos ambientales siga tiempos estandarizados para evitar lecturas erróneas por fluctuaciones momentáneas, lo que justifica técnicamente que el algoritmo procese de forma síncrona las señales de la terna de sensado en intervalos continuos y discretos de tiempo real, asegurando que las pruebas de verificación en el volumen de control tengan validez de ingeniería.

---

## Norma Técnica 3: Ley N° 28611 — Ley General del Ambiente

### Descripción
Es la norma ordenadora del marco jurídico ambiental en el Perú. Establece los principios rectores que consagran el derecho irrenunciable de toda persona a gozar de un entorno saludable, equilibrado y adecuado para el desarrollo de la vida. Asimismo, determina la obligación de las instituciones y ciudadanos de asegurar de manera preventiva la conservación de los recursos y la protección de la salud humana individual y colectiva frente a riesgos de contaminación.

### Aporte al proyecto
* **Fundamento Ético e Institucional:** Constituye el respaldo legal supremo que justifica el desarrollo del proyecto como una solución de democratización tecnológica. Al establecer que el control de los riesgos atmosféricos interiores es una responsabilidad vinculada a la prevención de la salud pública, eleva nuestra propuesta hacia un Sistema de Gestión Autónoma enfocado en reducir las brechas de vulnerabilidad en espacios cerrados públicos de alta ocupación.

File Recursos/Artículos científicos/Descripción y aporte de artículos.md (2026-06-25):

# 📑 Descripción y Aportes de Artículos Científicos — Equipo 13

En esta sección se detalla el análisis exhaustivo de los artículos científicos indizados utilizados como la base de conocimiento para el desarrollo de **Eco-Vent 13** bajo la metodología **VDI 2206**. Cada artículo aporta evidencia cuantitativa que convalida el hardware, la programación de la lógica de control en el microcontrolador y el análisis de restricciones del prototipo.

<p align="center">
  <a href="https://pmc.ncbi.nlm.nih.gov/articles/PMC3548274/" target="_blank">
    
  </a>
  <a href="https://www.sciencedirect.com/science/article/abs/pii/S0360132311002617" target="_blank">
    
  </a>
  <a href="https://dialnet.unirioja.es/servlet/articulo?codigo=6171218" target="_blank">
    
  </a>
  <a href="https://www.mdpi.com/2071-1050/13/8/4139" target="_blank">
    
  </a>
  <a href="https://doi.org/10.1016/j.buildenv.2018.03.040" target="_blank">
    
  </a>
</p>

---

## Artículo 1: Is CO₂ an Indoor Pollutant? Direct Effects of Low-to-Moderate CO₂ Concentrations on Human Decision-Making Performance

* **Autores:** Usha Satish, Mark J. Mendell, Krishnamurthy Shekhar, Toshifumi Hotchi, Douglas Sullivan, Siegfried Streufert, and William J. Fisk.
* **Año / Revista:** 2012 | *Environmental Health Perspectives*
* **Descripción:** Estudio experimental controlado en cámara de simulación ambiental que aisló el Dióxido de Carbono (CO₂) como variable independiente pura, evaluando a 22 participantes expuestos de forma síncrona a niveles de 600, 1000 y 2500 ppm mediante pruebas neurocognitivas computarizadas.
* **Aporte directo al proyecto:**
    * **Fundamento de Automatización:** El paper demuestra que al alcanzar las 1000 ppm ocurren decrementos moderados significativos en la toma de decisiones, mientras que a 2500 ppm las reducciones son severas y disfuncionales. Esto convalida que al ser un contaminante invisible que degrada la cognición sin provocar alertas sensoriales inmediatas, los sistemas reactivos manuales fallan, justificando un lazo cerrado autónomo donde el dispositivo sustituya la intervención humana.
    * **Calibración Algorítmica:** Establece con precisión el umbral de activación del software en >= 1000 ppm para el sensor de calidad de aire, y el nivel de alerta crítica en el indicador visual en > 1500 ppm, correspondientes a las zonas de riesgo neurocognitivo validadas en la investigación.

---

## Artículo 2: Ventilation rates in schools and pupils' performance

* **Autores:** Zs. Bakó-Biró, D.J. Clements-Croome, N. Kochhar, H.B. Awbi, M.J. Williams.
* **Año / Revista:** 2011 | *Building and Environment*
* **Descripción:** Investigación experimental de campo con diseño cruzado repetido aplicada a más de 200 alumnos en 16 aulas de educación primaria en Inglaterra, donde se implementó un sistema de ventilación mecánica portátil para elevar el suministro de aire de 1 l/s a 8 l/s por persona.
* **Aporte directo al proyecto:**
    * **Justificación de Ventilación Forzada:** Demuestra de forma empírica que elevar el suministro de aire exterior mitiga los picos históricos de 5000 ppm de CO₂ y acelera de forma significativa la velocidad de respuesta correcta en pruebas de atención, memoria y reconocimiento verbal. Esto convalida el uso de ventilación mecánica controlada sobre el monitoreo pasivo.
    * **Validación Acústica:** Establece la restricción de diseño para proteger el entorno de estudio: el sistema mecánico no debe superar los 35 dB de ruido durante la operación, asegurando que la introducción de los extractores axiales no interfiera con la concentración ni las actividades académicas.

---

## Artículo 3: Análisis temporal y espacial de la calidad del aire determinado por material particulado PM10 y PM2.5 en Lima Metropolitana

* **Autor:** Sergio A. Pacsi Valdivia.
* **Año / Revista:** 2016 | *Anales Científicos (UNALM)*
* **Descripción:** Estudio empírico multianual (2001-2014) que procesa las bases de datos de las redes de monitoreo automático y semiautomático de DIGESA y SENAMHI distribuidas en Lima Metropolitana y el Callao.
* **Aporte directo al proyecto:**
    * **Dimensionamiento del Problema Local:** El artículo evidencia que los promedios anuales de material particulado superan de forma sostenida los Estándares de Calidad Ambiental (ENCA) del Perú y las guías de la OMS, señalando explícitamente a las zonas Sur, Este y Norte de Lima con las mayores concentraciones (superiores a 100 ug/m³). Esto fundamenta la urgencia de implementar el dispositivo en distritos de alta vulnerabilidad industrial y del transporte, como Villa María del Triunfo.
    * **Inclusión de Filtración Mecánica:** Detalla que la resuspensión de polvo debido a calles sin pavimentar eleva el PM10 grueso de forma crítica. Esto valida mecánicamente que el diseño del chasis vertical (220x220x110 mm) incorpore un ducto con filtración mecánica granular acoplado a la inyección, protegiendo los espacios interiores del ingreso de contaminantes externos.

---

## Artículo 4: Effects of Climatic Conditions, Season and Environmental Factors on CO₂ Concentrations in Naturally Ventilated Primary Schools in Chile

* **Autores:** Muriel Diaz, Mario Cools, Maureen Trebilcock, Beatriz Piderit-Moreno, Shady Attia.
* **Año / Revista:** 2021 | *Sustainability*
* **Descripción:** Análisis transversal basado en el monitoreo físico continuo de CO₂, temperatura y humedad relativa (intervalos de 5 minutos) en 8 escuelas de educación primaria libres de ventilación mecánica, aplicando Regresión Logística Binaria (BLR) para determinar la probabilidad de éxito en el control ambiental.
* **Aporte directo al proyecto:**
    * **Convalidación de la Lógica de Control:** El modelo demuestra una dependencia crítica entre la acumulación de gases y la temperatura interior (p-value < 0.05). En temporadas frías, la necesidad de conservar el calor anula la disposición a abrir ventanas, relegando la calidad del aire y provocando picos continuos de 5000 ppm de CO₂. Esto justifica la integración síncrona en el firmware de la terna de sensado (gases y temperatura): el sistema procesará simultáneamente las variables térmicas y químicas para ejecutar la renovación neumática de forma aislada, protegiendo la salud sin destruir el confort térmico.
    * **Especificación de Restricciones:** Avala que la ventilación pasiva es termodinámicamente incapaz de estabilizar el aire interior en ambientes de alta densidad escolar (densidades de 1.1 a 1.9 m²/alumno), validando la selección de un sistema mecatrónico autónomo.

---

## Artículo 5: Indoor air quality in classrooms: Environmental measures and effective ventilation rate modeling in urban elementary schools

* **Autores:** David L. Johnson, Robert A. Lynch, Evan L. Floyd, Jun Wang, Jacob N. Bartels.
* **Año / Revista:** 2018 | *Building and Environment*
* **Descripción:** Evaluación de la calidad del aire interior en aulas de 12 escuelas urbanas midiendo contaminantes químicos y físicos durante periodos de 24 horas por estación, modelando las tasas de ventilación fresca efectiva mediante un enfoque matemático de balance de masa transitorio.
* **Aporte directo al proyecto:**
    * **Arquitectura del Flujo Lógico:** El estudio demuestra que las concentraciones de CO₂ en aulas rara vez alcanzan condiciones de equilibrio dinámico (estado estable), validando que el modelado lógico de Eco-Vent debe estructurarse analizando los flujos en intervalos discretos de acumulación y decaimiento. Esto justifica el uso de un banco de relés independientes para gestionar cada ventilador de forma aislada, asegurando el control de los flujos físicos sin caídas de tensión.
    * **Modelado del Volumen de Control:** Proporciona el marco matemático transitorio para verificar experimentalmente que la tasa de renovación de aire real de la arquitectura Push-Pull (4 ventiladores axiales) mitiga eficazmente los contaminantes dentro del volumen de control nominal establecido de 30 m³.

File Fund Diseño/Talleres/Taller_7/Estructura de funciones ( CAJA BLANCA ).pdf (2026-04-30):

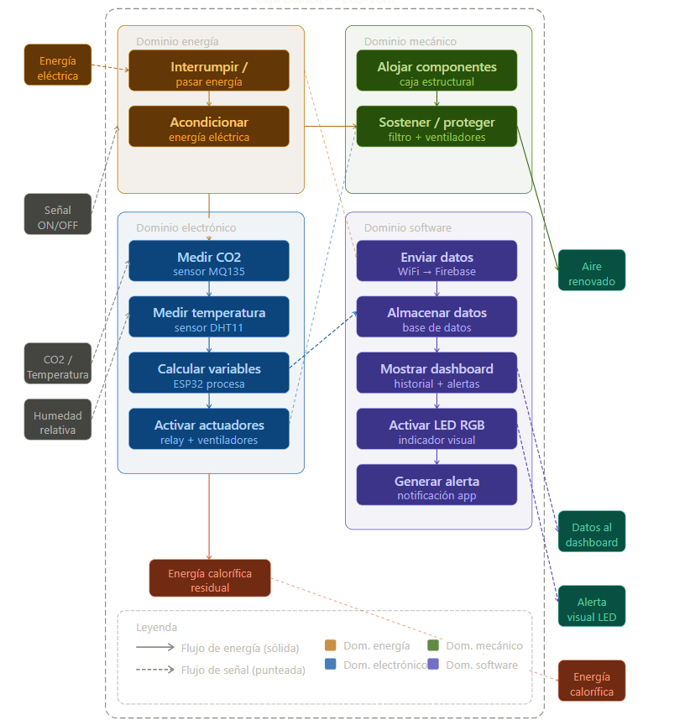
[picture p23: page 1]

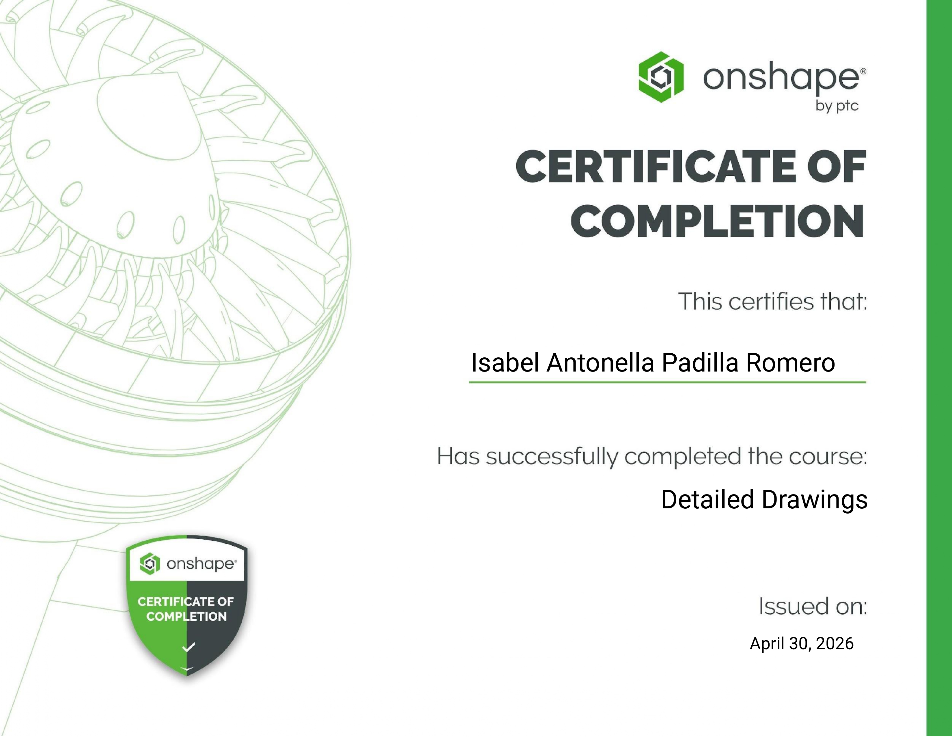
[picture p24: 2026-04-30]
Fund Diseño/Talleres/Taller_7/Certificados Onshape/Isabel Antonella Padilla Romero/Detailed Drawings - Isabel Antonella Padilla Romero.jpg

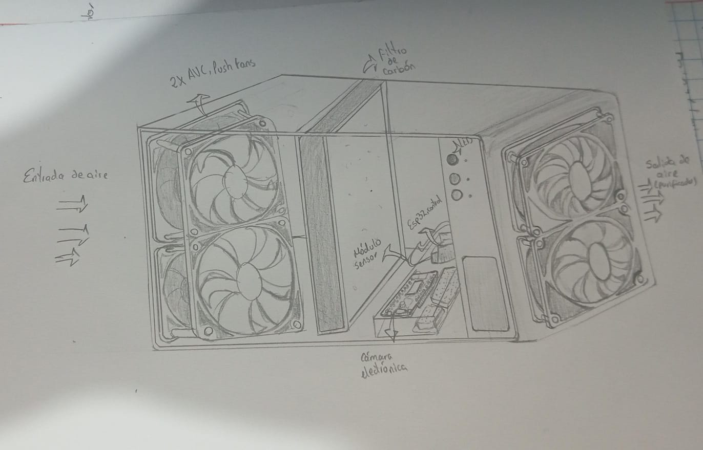
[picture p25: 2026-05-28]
Fund Diseño/Talleres/Taller_7/EcoVent_Boceto_Final.jpg

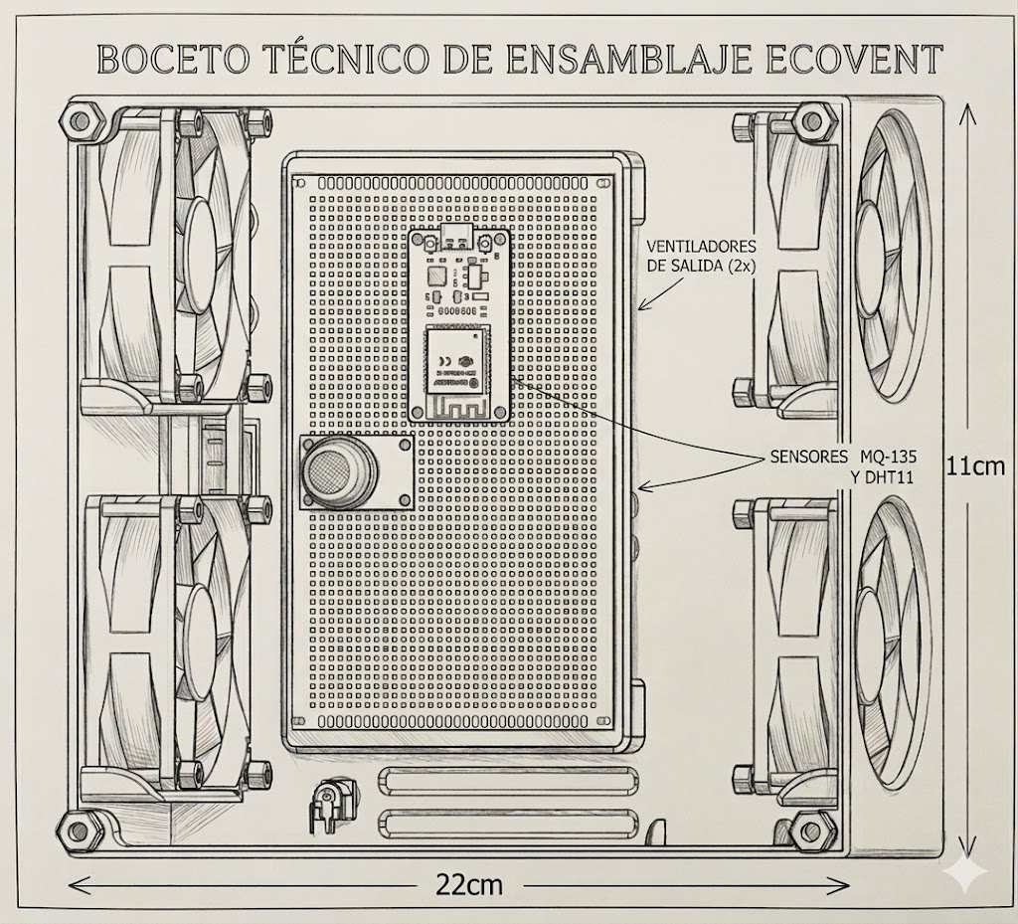
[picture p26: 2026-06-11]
Fund Diseño/Entregables/Entregable 3/Bocetos/Boceto Vista 1.jpg

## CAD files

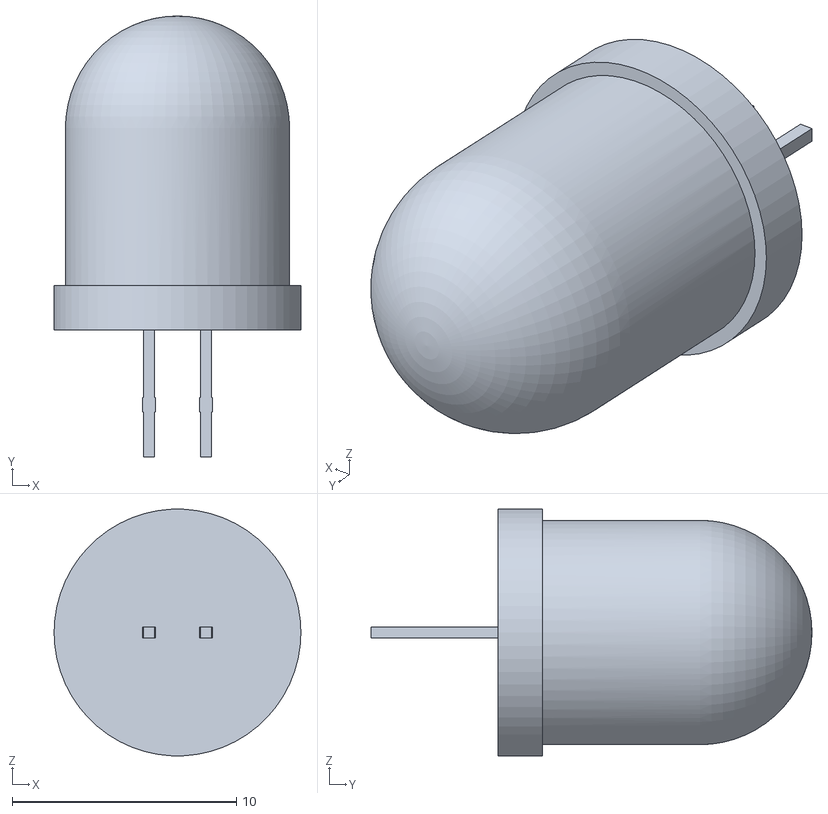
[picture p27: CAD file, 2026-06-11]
Fund Diseño/Entregables/Entregable 3/Modelado 3D/Modelos STL Importados/LED 10mm Green.stl
11.0 x 19.7 x 11.0

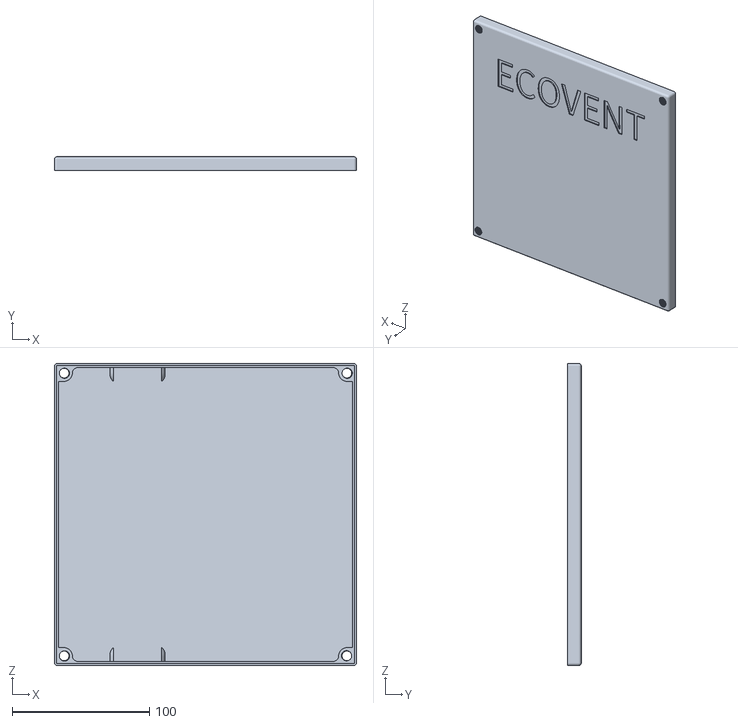
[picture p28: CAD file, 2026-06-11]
Proyecto/MóduloMecánico/VFINAL/Onshape/Partes/ECOVENT Tapa de la Caja.stl
220.0 x 10.0 x 220.0

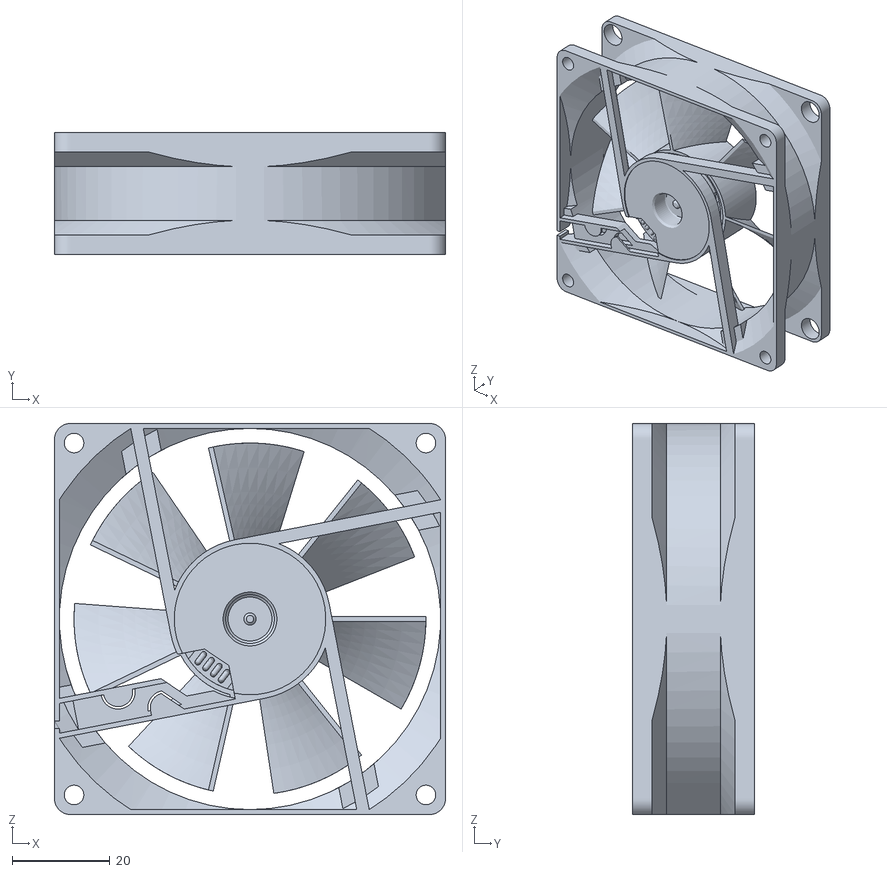
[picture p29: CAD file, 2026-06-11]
Fund Diseño/Entregables/Entregable 3/Modelado 3D/Modelos STL Importados/8x8 cm 12V Fan.stl
80.0 x 25.0 x 80.0

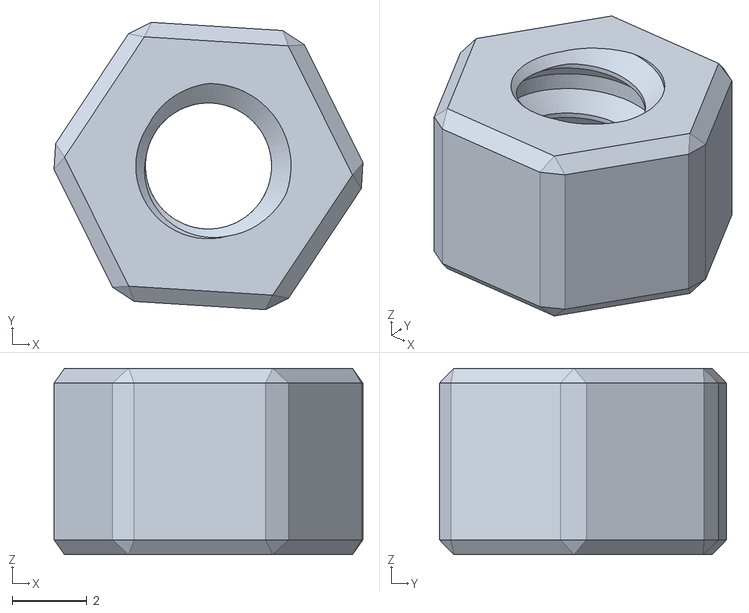
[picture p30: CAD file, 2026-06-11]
Proyecto/MóduloMecánico/VFINAL/Onshape/Partes/ECOVENT Tuerca de Ventiladores.stl
8.29 x 7.71 x 5.00

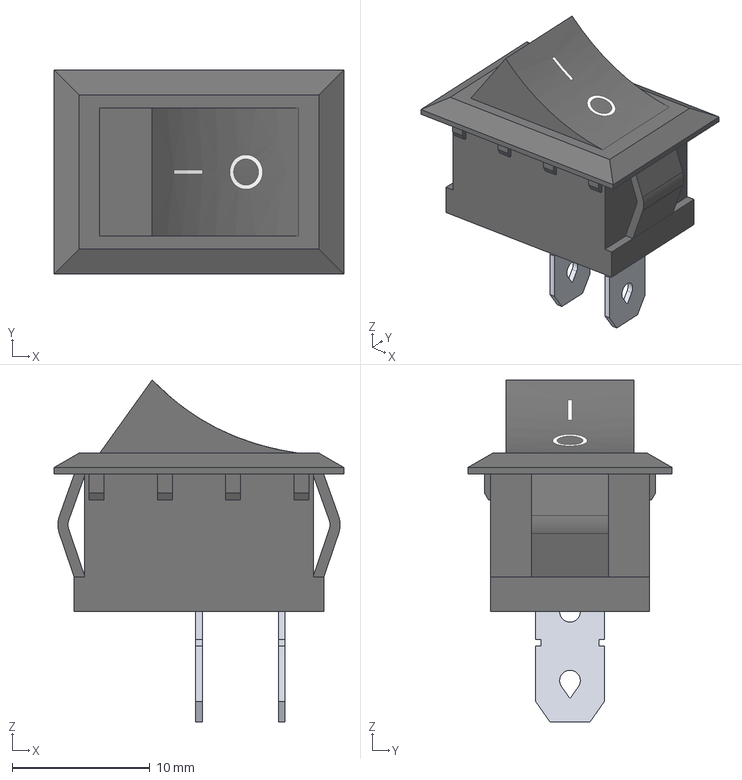
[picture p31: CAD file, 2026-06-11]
Fund Diseño/Entregables/Entregable 3/Modelado 3D/Modelos STL Importados/RockerSwitch.step
21.0 x 14.8 x 24.8 mm

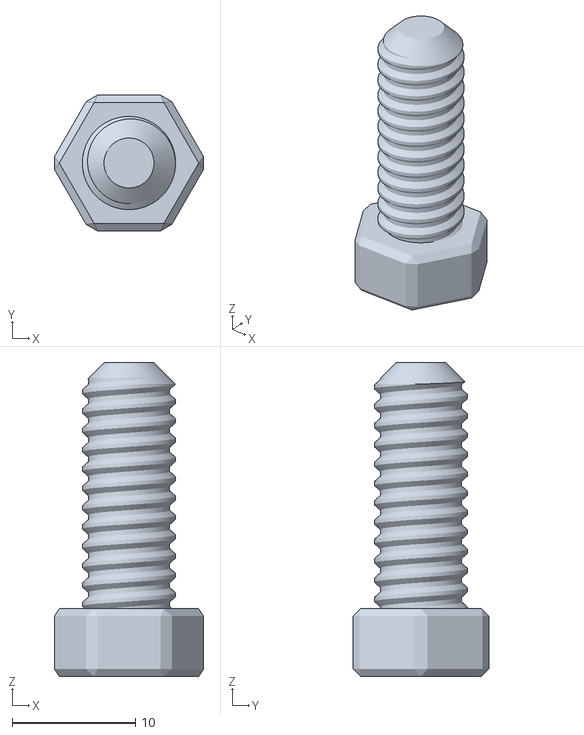
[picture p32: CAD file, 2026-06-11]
Proyecto/MóduloMecánico/VFINAL/Onshape/Partes/ECOVENT Tornillo de la Tapa.stl
12.1 x 11.0 x 25.5

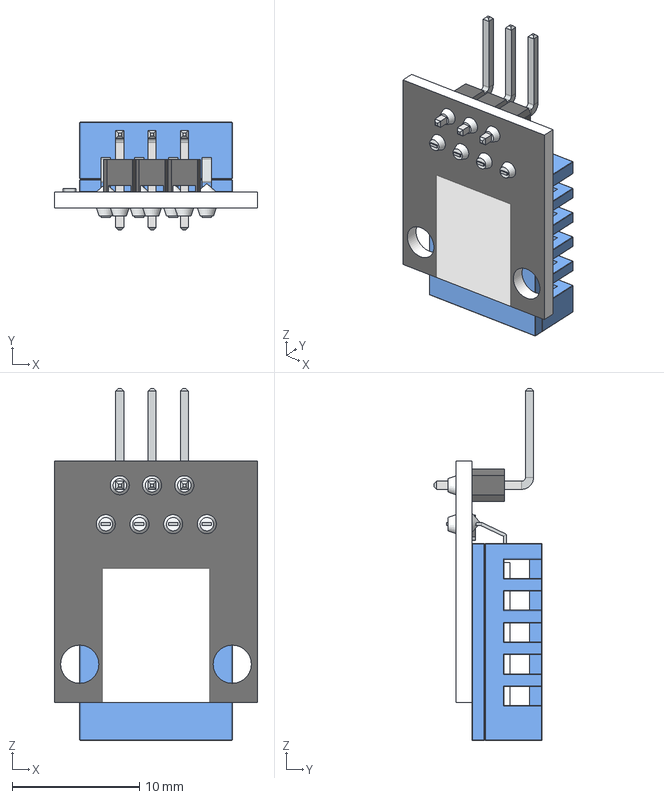
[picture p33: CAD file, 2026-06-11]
Fund Diseño/Entregables/Entregable 3/Modelado 3D/Modelos STL Importados/KY-015 (1).step
16.0 x 8.50 x 27.7 mm

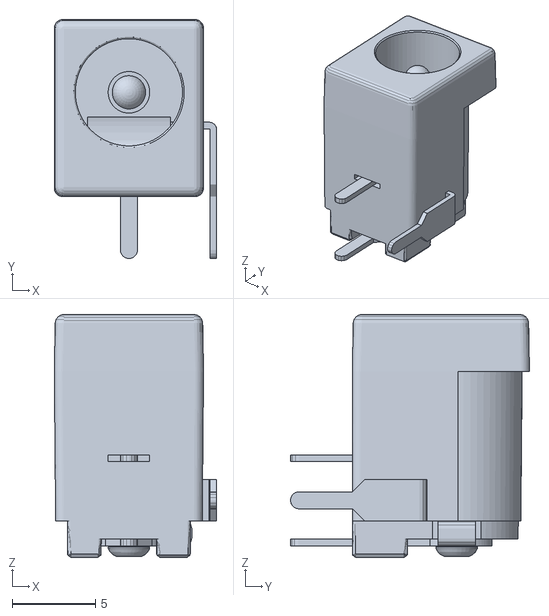
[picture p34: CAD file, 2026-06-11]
Fund Diseño/Entregables/Entregable 3/Modelado 3D/Modelos STL Importados/DC Power Jack 5.5mm x 2.1mm.stl
9.77 x 14.4 x 14.6

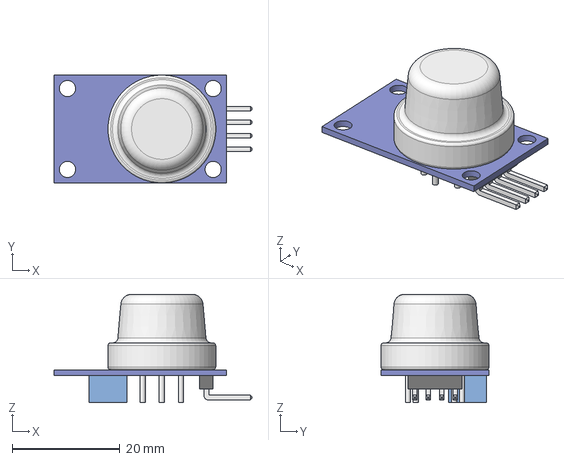
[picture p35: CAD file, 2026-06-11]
Fund Diseño/Entregables/Entregable 3/Modelado 3D/Modelos STL Importados/MQ135_sensor.step
36.7 x 20.0 x 20.1 mm

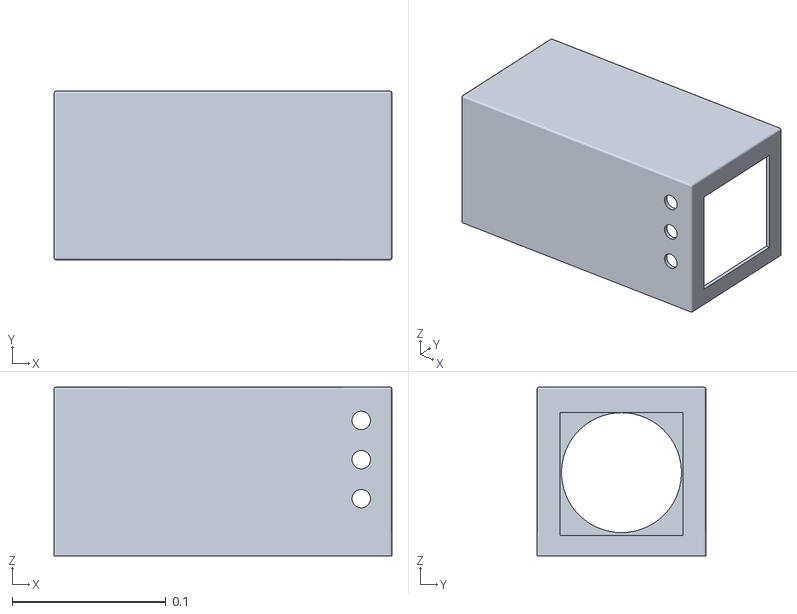
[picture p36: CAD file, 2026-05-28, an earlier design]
Proyecto/MóduloMecánico/V 1.0/Onshape/PARTES/EcoVent - Base Superior.stl
0.22 x 0.11 x 0.11

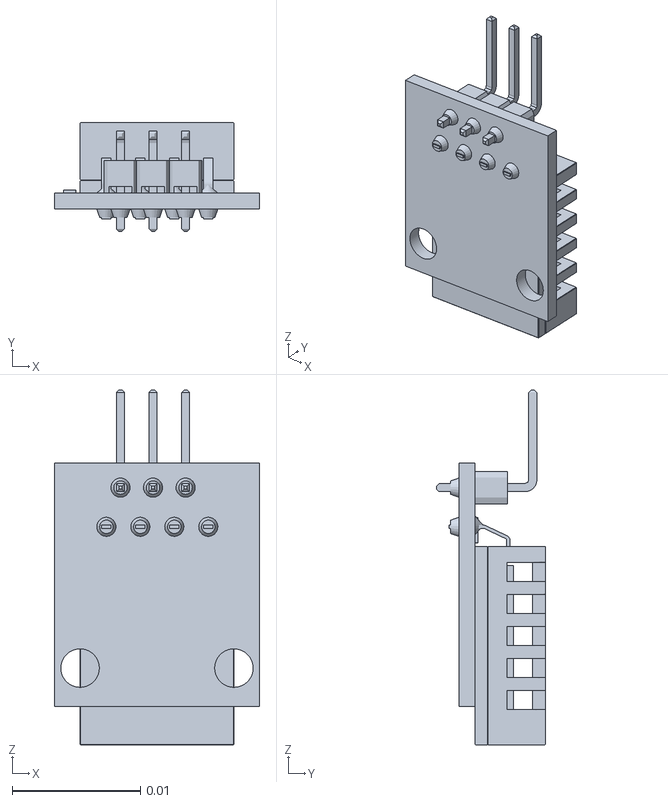
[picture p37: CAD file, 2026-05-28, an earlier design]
Proyecto/MóduloMecánico/V 1.0/Onshape/PARTES/KY-015.stl
0.016 x 0.0085 x 0.0277

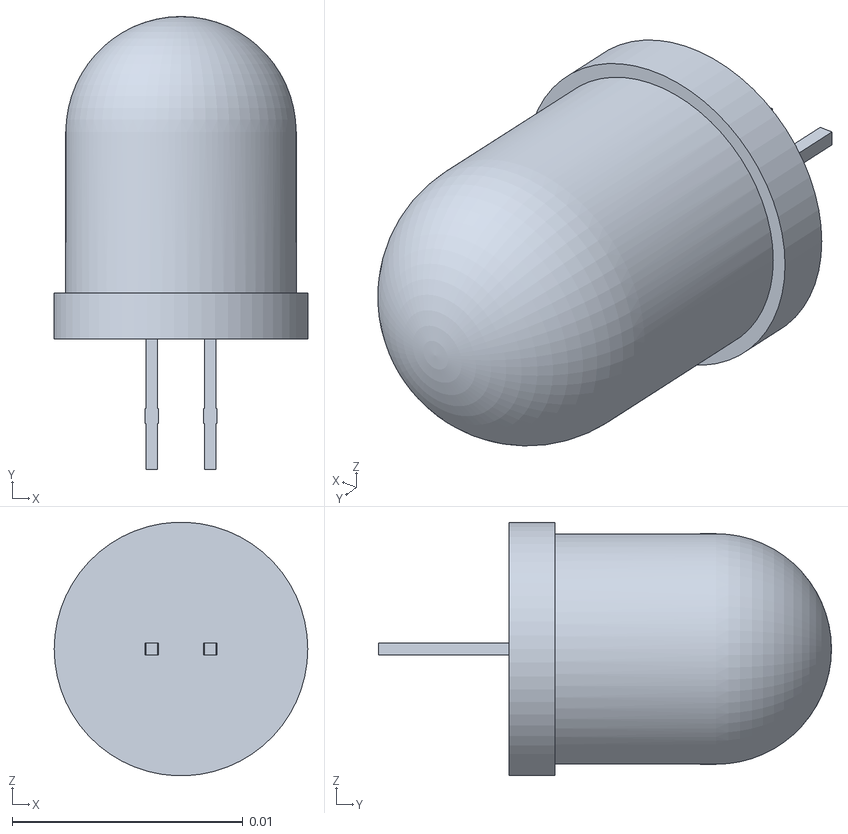
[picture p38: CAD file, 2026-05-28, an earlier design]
Proyecto/MóduloMecánico/V 1.0/Onshape/PARTES/LED 10mm Green.stl
0.011 x 0.0197 x 0.011

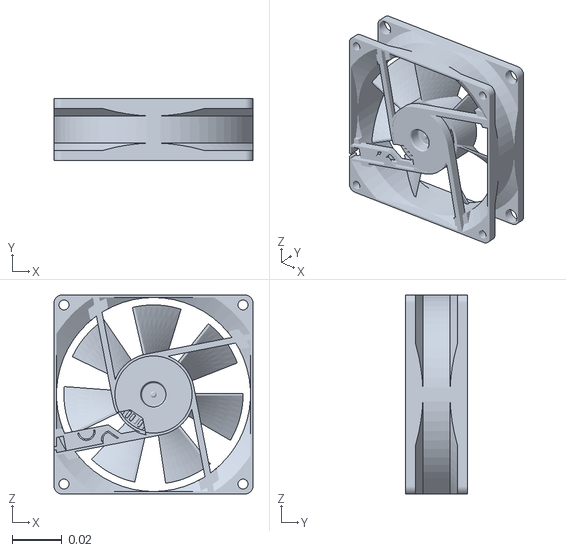
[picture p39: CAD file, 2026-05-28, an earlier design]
Proyecto/MóduloMecánico/V 1.0/Onshape/PARTES/8x8 cm 12V Fan.stl
0.08 x 0.025 x 0.08

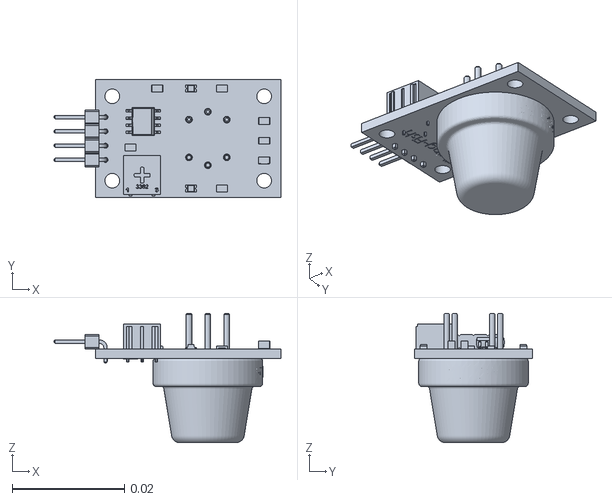
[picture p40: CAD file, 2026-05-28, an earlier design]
Proyecto/MóduloMecánico/V 1.0/Onshape/PARTES/MQ135_MH_sensor_with_socket_pins_90grd.stl
0.0404 x 0.021 x 0.023

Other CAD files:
Fund Diseño/Entregables/Entregable 3/Modelado 3D/Modelos STL Importados/RockerSwitch.stl
Proyecto/MóduloMecánico/V 1.0/Onshape/PARTES/ESP32 dev Kit v1.stl
Proyecto/MóduloMecánico/V 1.0/Onshape/PARTES/EcoVent - Base Inferior.stl
Proyecto/MóduloMecánico/V 1.0/Onshape/PARTES/EcoVent - TAPA.stl

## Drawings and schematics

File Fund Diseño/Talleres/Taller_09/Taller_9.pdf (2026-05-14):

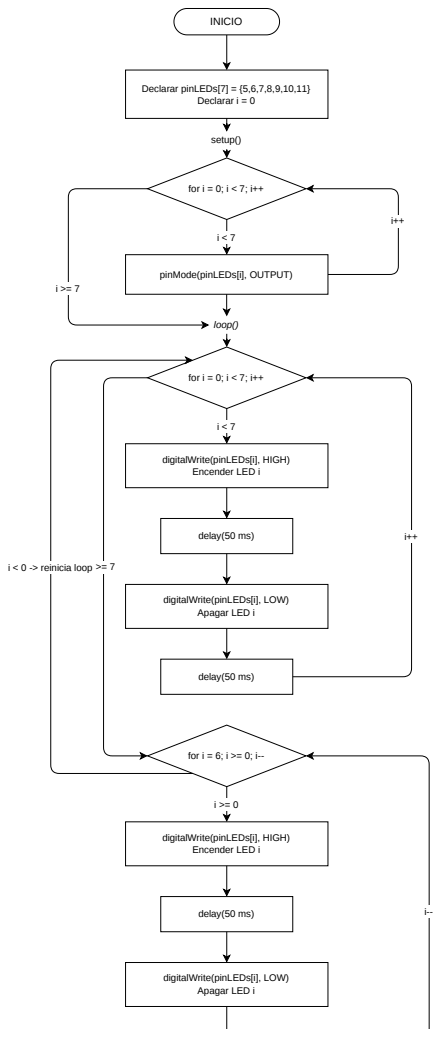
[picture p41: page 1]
Declarar pinLEDs[7] = {5,6,7,8,9,10,11} Declarar i = 0; setup(); for i = 0; i < 7; i++; loop(); delay(50 ms); Apagar LED i; for i = 6; i >= 0; i--; i < 0 -> reinicia loop; INICIO

pinMode(pinLEDs[i], OUTPUT)

digitalWrite(pinLEDs[i], HIGH)
Encender LED i

digitalWrite(pinLEDs[i], LOW)

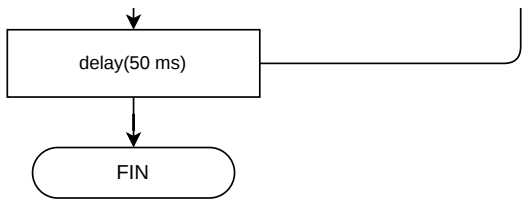
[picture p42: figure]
delay(50 ms); FIN

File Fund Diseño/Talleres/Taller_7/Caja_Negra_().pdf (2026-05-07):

# ENTRADA ECO-VENT

# SALIDA

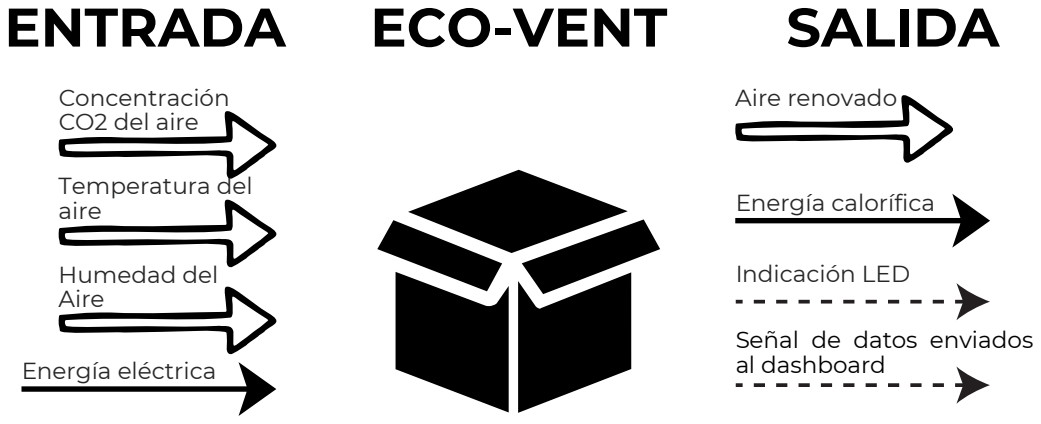
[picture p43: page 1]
Energía eléctrica; Aire renovado; Energía calorífica; Indicación LED; Temperatura del aire; Humedad del Aire; Concentración CO2 del aire

Señal de datos enviados
al dashboard

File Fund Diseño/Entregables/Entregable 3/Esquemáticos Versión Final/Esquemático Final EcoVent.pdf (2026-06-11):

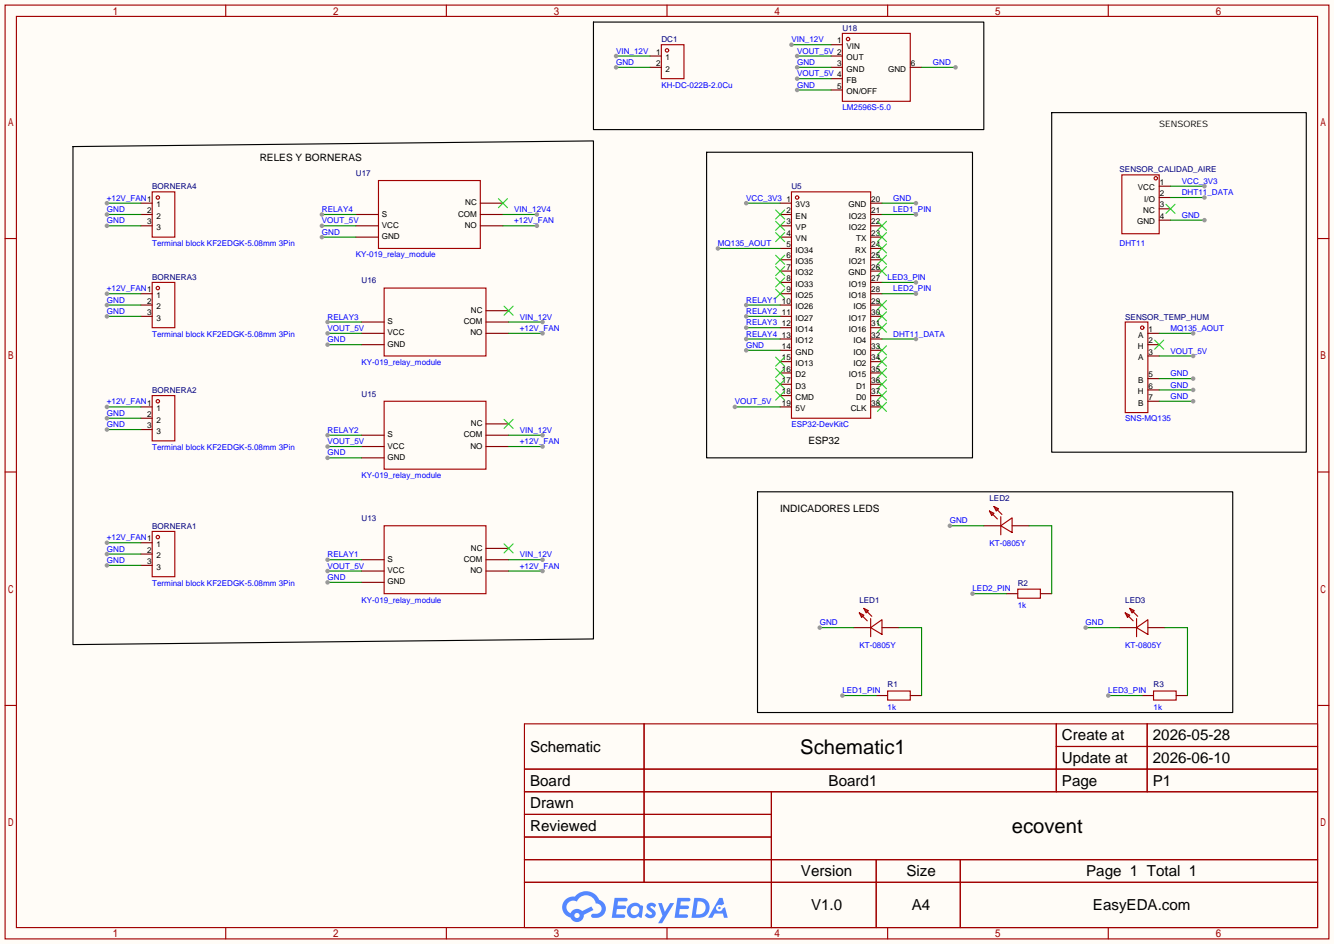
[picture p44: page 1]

Schematic | Schematic1 | Create at | 2026-05-28

Update at | 2026-06-10

Board | Board1 | Page | P1
Drawn | | ecovent
Reviewed

Version | Size | Page 1 Total 1
V1.0 | A4 | EasyEDA.com

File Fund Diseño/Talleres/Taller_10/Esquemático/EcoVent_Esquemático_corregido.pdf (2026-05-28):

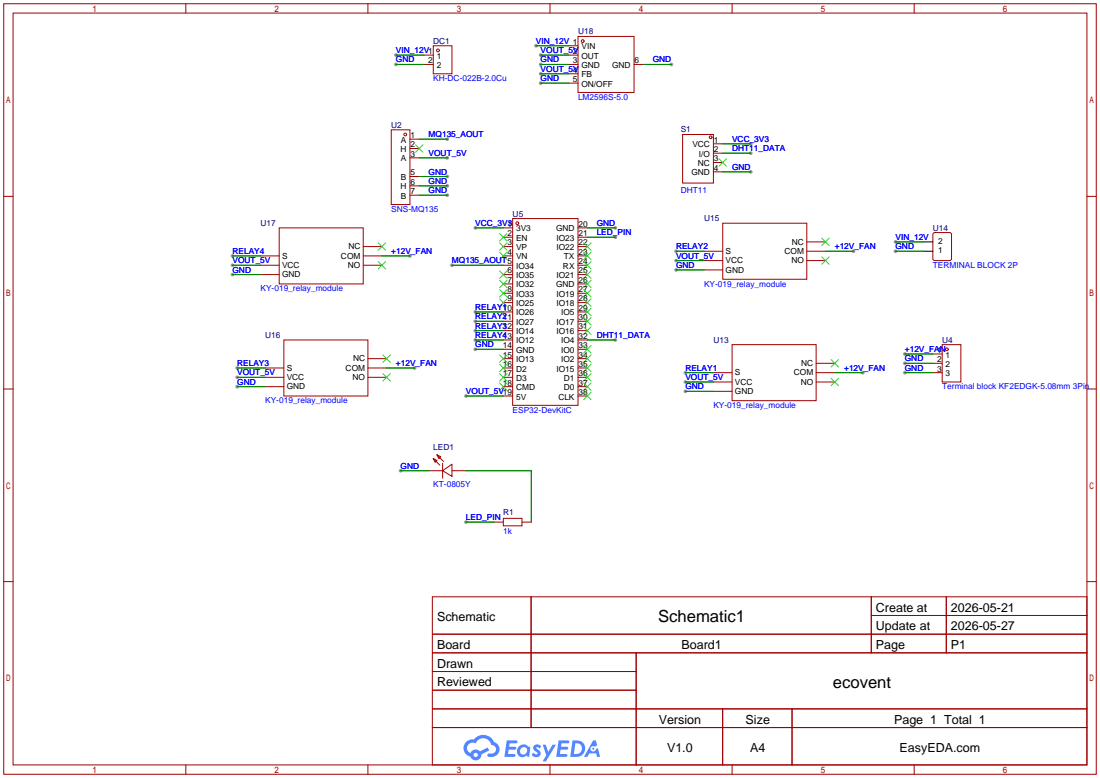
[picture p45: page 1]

Schematic | Schematic1 | Create at | 2026-05-21

Update at | 2026-05-27

Board | Board1 | Page | P1
Drawn | | ecovent
Reviewed

Version | Size | Page 1 Total 1
V1.0 | A4 | EasyEDA.com

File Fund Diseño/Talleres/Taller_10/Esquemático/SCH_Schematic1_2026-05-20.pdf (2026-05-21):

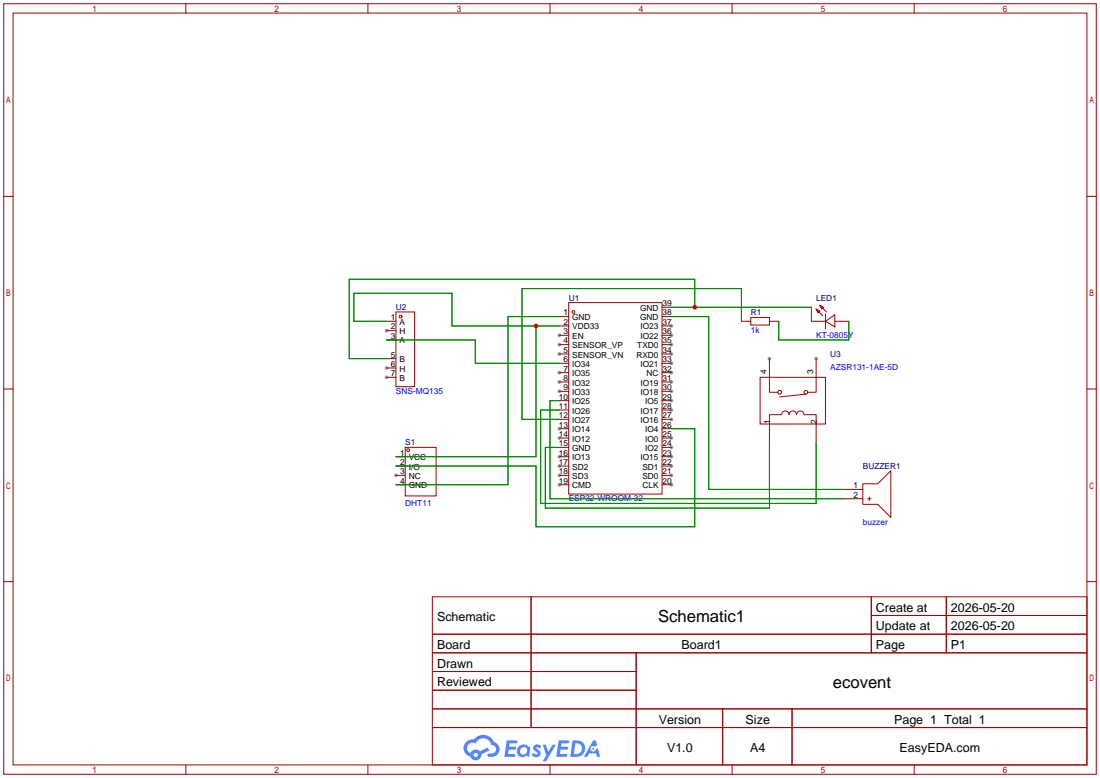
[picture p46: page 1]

Schematic | Schematic1 | Create at | 2026-05-20

Update at | 2026-05-20

Board | Board1 | Page | P1
Drawn | | ecovent
Reviewed

Version | Size | Page 1 Total 1
V1.0 | A4 | EasyEDA.com

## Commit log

2026-03-20 Estructura inicial según guía de la UPCH
2026-03-20 Limpieza y organización de carpetas acorde al modelo oficial
2026-03-20 Estructura de subcarpetas según ejemplo
2026-03-20 Edición de estructura
2026-03-20 Eliminación de un archivo
2026-03-26 Isabel Padilla: Estructura final con fotografía oficial e integrantes y refinamiento de formato en README
2026-04-11 Taller 4: Búsqueda de Patentes
2026-04-11 Imágenes de referencia de Patentes
2026-04-11 Taller 4: Búsqueda de Patentes con imágenes
2026-04-11 Taller 4: Búsqueda de Patentes con imágenes corregido
    Updated image syntax for patent diagrams to use HTML format.
2026-04-11 Taller 4: Búsqueda de Patentes con imágenes corregido
2026-04-23 Renombrar EcoVent-Pitch.pdf a Taller_6.md
2026-04-23 Corrección de numeración de Taller_5
    Se reemplaza el Taller_5 vacío con el contenido previamente agregado como Taller_6, corrigiendo la numeración de los talleres.
2026-04-24 Add Desk Research
    Se añadió una investigación documental detallada para el proyecto del sistema de gestión del aire, que incluye la definición del problema, la matriz de investigación, la lista de requisitos, la estructura funcional, la reformulación de la oportunidad de diseño y las conclusiones.
2026-04-28 Revisar y ampliar la sección de referencias bibliográficas.
    Se actualizó la sección de referencias con un nuevo formato y se agregaron referencias adicionales relacionadas con estándares internacionales, la calidad del aire a nivel nacional en Perú, los impac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
2026-04-30 Add files via upload
    Estructura de Funciones ( CAJA BLANCA )
2026-06-24 Agregar foto de integrante
2026-06-25 Rename README.md to Descripción y aporte de artículos.md
2026-06-25 Update Descripción y aporte de artículos.md
2026-06-25 Update and rename README.md to Descripción y aporte de normas.md
2026-06-25 Update and rename README.md to Descripción y aporte de tesis.md
2026-06-25 Update and rename README.md to Descripción y aporte de productos.md
